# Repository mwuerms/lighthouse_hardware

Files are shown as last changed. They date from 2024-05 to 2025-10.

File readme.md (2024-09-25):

# Lighthouse - Hardware

## basic concept

+ lighthouse
+ buoy: hand sender, ble advertising

## lighthouse - electronics

### main board

- RF-MCU: nRF52840: [NINA-B302-00B Module](https://www.mouser.ch/ProductDetail/377-NINA-B302-00B) (ublox)
  - SWDIO connector (50 mil header)
  - RTC (optional): i2c + backup battery CV
  - sound module: [DFPlayer mini](https://wiki.dfrobot.com/DFPlayer_Mini_SKU_DFR0299)
  - display 1: display time
  - display 2: lighting, simulate sunrise
  - Buttons
  - Sensors
    - ambient light sensor (ALS)
      - [VEML7700-TR](https://www.mouser.ch/ProductDetail/78-VEML7700-TR)
      - [TMD37253M](https://www.mouser.ch/ProductDetail/985-TMD37253M) much more than ALS, also proximity and color sensor
      - also maybe [VEML3235](https://www.mouser.ch/ProductDetail/78-VEML3235), [VEML6035](https://www.mouser.ch/ProductDetail/78-VEML6035)
    - rh sensor
      - [SHT40-AD1B-R2](https://www.mouser.ch/ProductDetail/403-SHT40-AD1B-R2)
    - p sensor
      - [DPS368XTSA1](https://www.mouser.ch/ProductDetail/726-DPS368XTSA1)
    - microphone, maybe implement a "do I snore" functionality
      - [CMM-4030DT-26354-TR](https://www.mouser.ch/ProductDetail/490-CMM4030DT26354TR)

### display

- addressable LEDs: [IN-PI22TAT5R5G5B](https://www.mouser.ch/ProductDetail/743-IN-PI22TAT5R5G5B)

### buoy - electronics

- RF-MCU: nRF52811 module [ISP1907-LL-RS](https://www.mouser.ch/ProductDetail/359-ISP1907-LL-RS)
- battery CR2032
- vibration sensor [Adafruit 2384](https://www.mouser.ch/ProductDetail/485-2384)
- button PTS526 [PTS526 SK15 SMTR2 LFS](https://www.mouser.ch/ProductDetail/611-PTS526SK15SMR2L)
- SWDIO connector (50 mil header)

#### schematics

buoy will be soldered together using wire only, no pcb for this.

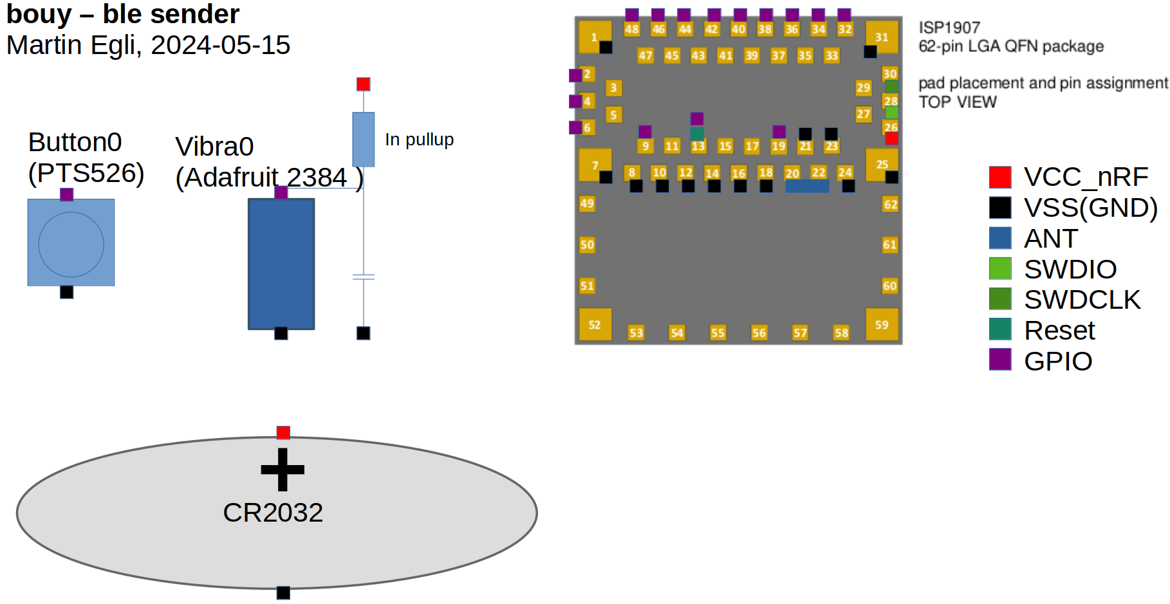
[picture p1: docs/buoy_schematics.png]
buoy_schematics


# links

just a collection of (maybe) useful links

- [markdown cheat sheet](https://www.markdownguide.org/cheat-sheet/)

# ideas

- add many sensors like
  - microphone, analyze snoring
- add memory/flash to log
  - sensor values
  - events
  - errors, ...

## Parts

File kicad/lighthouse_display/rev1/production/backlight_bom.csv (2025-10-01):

Designator | Footprint | Quantity | Value | LCSC Part #
C1 | 0603 | 1 | CL10B104KA8NNNC | C1590
C10 | 0603 | 1 | CL10B104KA8NNNC | C1590
C11 | 0805 | 1 | CL21B105KAFNFNE | C1712
C2 | 0805 | 1 | CL21B103KBANNNC | C1710
C3 | 0603 | 1 | 0603B512K500NT | C1587
C4 | 0805 | 1 | CL21B105KAFNFNE | C1712
C5 | 0805 | 1 | CL21B103KBANNNC | C1710
C6 | 0603 | 1 | CL10B104KA8NNNC | C1590
C7 | 0805 | 1 | CL21B103KBANNNC | C1710
C8 | 0603 | 1 | CL10B104KA8NNNC | C1590
C9 | 0603 | 1 | CL10B104KA8NNNC | C1590
D1 | 1206 | 1 | KT-1206Y | C2298
D10 | 1206 | 1 | KT-1206Y | C2298
D100 | SOD-323F | 1 | PMEG4010CEJ,115 | C50704
D101 | 1206 | 1 | XL-3216WWC | C965830
D102 | 1206 | 1 | XL-3216WWC | C965830
D103 | 1206 | 1 | XL-3216WWC | C965830
D104 | 1206 | 1 | XL-3216WWC | C965830
D105 | 1206 | 1 | XL-3216WWC | C965830
D106 | 1206 | 1 | XL-3216WWC | C965830
D11 | 1206 | 1 | KT-1206Y | C2298
D12 | 1206 | 1 | KT-1206R | C49018
D13 | 1206 | 1 | KT-1206R | C49018
D14 | 1206 | 1 | KT-1206Y | C2298
D15 | 1206 | 1 | KT-1206Y | C2298
D16 | 1206 | 1 | KT-1206R | C49018
D17 | 1206 | 1 | KT-1206R | C49018
D18 | 1206 | 1 | KT-1206Y | C2298
D19 | 1206 | 1 | KT-1206Y | C2298
D2 | 1206 | 1 | KT-1206Y | C2298
D20 | 1206 | 1 | KT-1206Y | C2298
D21 | 1206 | 1 | KT-1206R | C49018
D22 | 1206 | 1 | KT-1206R | C49018
D23 | 1206 | 1 | KT-1206Y | C2298
D24 | 1206 | 1 | KT-1206Y | C2298
D25 | 1206 | 1 | KT-1206R | C49018
D26 | 1206 | 1 | KT-1206R | C49018
D27 | 1206 | 1 | KT-1206Y | C2298
D28 | 1206 | 1 | KT-1206Y | C2298
D29 | 1206 | 1 | KT-1206R | C49018
D3 | 1206 | 1 | KT-1206Y | C2298
D30 | 1206 | 1 | KT-1206R | C49018
D31 | 1206 | 1 | KT-1206Y | C2298
D32 | 1206 | 1 | KT-1206Y | C2298
D33 | 1206 | 1 | KT-1206R | C49018
D34 | 1206 | 1 | KT-1206R | C49018
D35 | 1206 | 1 | KT-1206Y | C2298
D36 | 1206 | 1 | KT-1206Y | C2298
D37 | 1206 | 1 | KT-1206Y | C2298
D38 | 1206 | 1 | KT-1206R | C49018
D39 | 1206 | 1 | KT-1206R | C49018
D4 | 1206 | 1 | KT-1206Y | C2298
D40 | 1206 | 1 | KT-1206Y | C2298
D41 | 1206 | 1 | KT-1206Y | C2298
D42 | 1206 | 1 | KT-1206R | C49018
D43 | 1206 | 1 | KT-1206R | C49018
D44 | 1206 | 1 | KT-1206Y | C2298
D45 | 1206 | 1 | KT-1206Y | C2298
D46 | 1206 | 1 | KT-1206R | C49018
D47 | 1206 | 1 | KT-1206R | C49018
D48 | 1206 | 1 | KT-1206Y | C2298
D49 | 1206 | 1 | KT-1206Y | C2298
D5 | 1206 | 1 | KT-1206Y | C2298
D50 | 1206 | 1 | KT-1206Y | C2298
D51 | 1206 | 1 | KT-1206R | C49018
D52 | 1206 | 1 | KT-1206R | C49018
D53 | 1206 | 1 | KT-1206Y | C2298
D54 | 1206 | 1 | KT-1206Y | C2298
D55 | 1206 | 1 | KT-1206Y | C2298
D56 | 1206 | 1 | KT-1206Y | C2298
D57 | 1206 | 1 | KT-1206R | C49018
D58 | 1206 | 1 | KT-1206R | C49018
D59 | 1206 | 1 | KT-1206R | C49018
D6 | 1206 | 1 | KT-1206Y | C2298
D60 | 1206 | 1 | KT-1206R | C49018
D61 | 1206 | 1 | KT-1206R | C49018
D62 | 1206 | 1 | KT-1206R | C49018
D63 | 1206 | 1 | KT-1206R | C49018
D64 | 1206 | 1 | XL-3216WWC | C965830
D65 | 1206 | 1 | XL-3216WWC | C965830
D66 | 1206 | 1 | XL-3216WWC | C965830
D67 | 1206 | 1 | XL-3216WWC | C965830
D68 | 1206 | 1 | XL-3216WWC | C965830
D69 | 1206 | 1 | XL-3216WWC | C965830
D7 | 1206 | 1 | KT-1206Y | C2298
D70 | 1206 | 1 | XL-3216WWC | C965830
D71 | 1206 | 1 | XL-3216WWC | C965830
D72 | 1206 | 1 | XL-3216WWC | C965830
D73 | 1206 | 1 | XL-3216WWC | C965830
D74 | 1206 | 1 | XL-3216WWC | C965830
D75 | 1206 | 1 | XL-3216WWC | C965830
D76 | 1206 | 1 | XL-3216WWC | C965830
D77 | 1206 | 1 | XL-3216WWC | C965830
D78 | 1206 | 1 | XL-3216WWC | C965830
D79 | 1206 | 1 | XL-3216WWC | C965830
D8 | 1206 | 1 | KT-1206R | C49018
D80 | 1206 | 1 | XL-3216WWC | C965830
D81 | 1206 | 1 | XL-3216WWC | C965830
D82 | 1206 | 1 | XL-3216WWC | C965830
D83 | 1206 | 1 | XL-3216WWC | C965830
D84 | 1206 | 1 | XL-3216WWC | C965830
D85 | 1206 | 1 | XL-3216WWC | C965830
D86 | 1206 | 1 | XL-3216WWC | C965830
D87 | 1206 | 1 | XL-3216WWC | C965830
D88 | 1206 | 1 | XL-3216WWC | C965830
D89 | 1206 | 1 | XL-3216WWC | C965830
D9 | 1206 | 1 | KT-1206R | C49018
D90 | 1206 | 1 | XL-3216WWC | C965830
D91 | 1206 | 1 | XL-3216WWC | C965830
D92 | 1206 | 1 | XL-3216WWC | C965830
D93 | 1206 | 1 | XL-3216WWC | C965830
D94 | 1206 | 1 | XL-3216WWC | C965830
D95 | 1206 | 1 | XL-3216WWC | C965830
D96 | 1206 | 1 | XL-3216WWC | C965830
D97 | 1206 | 1 | XL-3216WWC | C965830
D98 | 1206 | 1 | XL-3216WWC | C965830
D99 | 1206 | 1 | XL-3216WWC | C965830
IC1 | WSON-6-EP | 1 | OPT3004DNPR | C2655153
R1 | 0603 | 1 | 0603WAJ0135T5E | C12647
R10 | 0603 | 1 | 0603WAF1004T5E | C22935
R11 | 0603 | 1 | 0603WAF1004T5E | C22935
R12 | 0603 | 1 | 0603WAF2002T5E | C4184
R2 | 0603 | 1 | 0603WAF5102T5E | C23196
R3 | 0603 | 1 | 0603WAF1004T5E | C22935
R4 | 0603 | 1 | 0603WAF6802T5E | C23231
R5 | 0603 | 1 | 0603WAF1004T5E | C22935
R8 | 0603 | 1 | 0603WAF1004T5E | C22935
R9 | 0603 | 1 | 0603WAF1004T5E | C22935
U2 | WQFN-16-EP | 1 | TPS61176RTER | C117008
U3 | DFN-4-EP | 1 | SHTC3-TR-10KS | C2880044

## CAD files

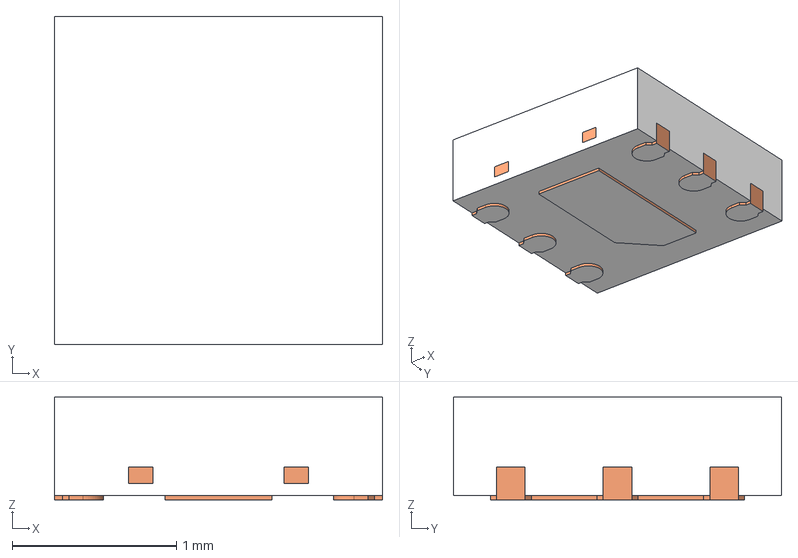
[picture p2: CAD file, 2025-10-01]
kicad/lighthouse.3d/USON-6.stp
2.00 x 2.00 x 0.625 mm
BODY-SON
FRAME-DNP0006A
PIN1-ID
DIE
BOND_WIRE_AF0
BOND_WIRE_AF1
BOND_WIRE_AF2
BOND_WIRE_AF3
BOND_WIRE_AF4
BOND_WIRE_AF5

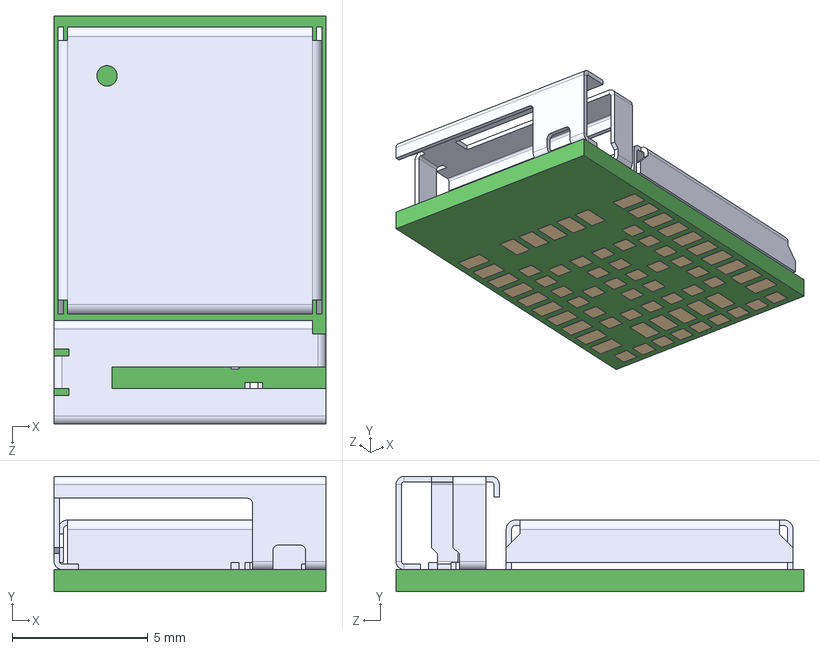
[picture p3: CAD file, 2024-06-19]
kicad/lighthouse_base/NINA-B312/NINA-B312.step
10.0 x 4.23 x 15.0 mm

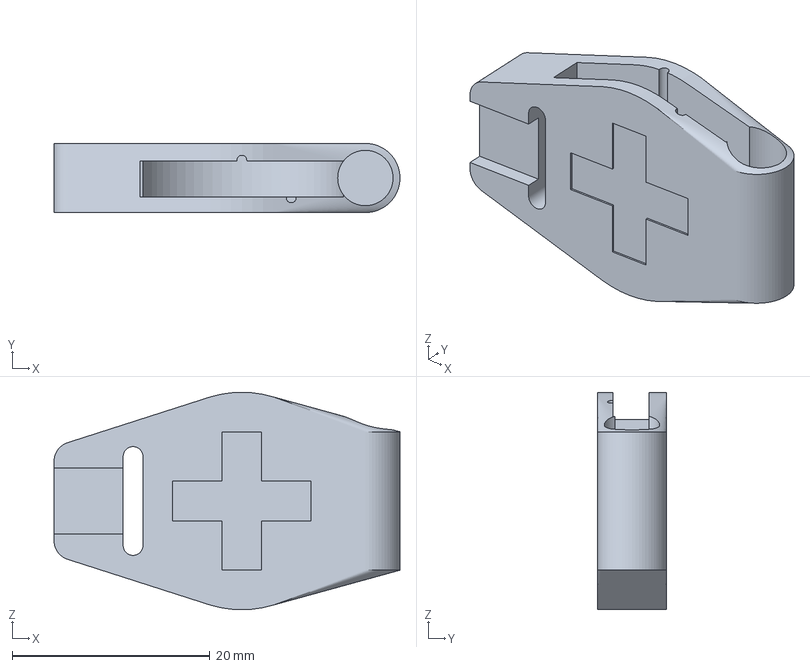
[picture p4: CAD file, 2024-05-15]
scad/buoy/buoy_v1.0.3mf
35.0 x 7.00 x 22.0 mm

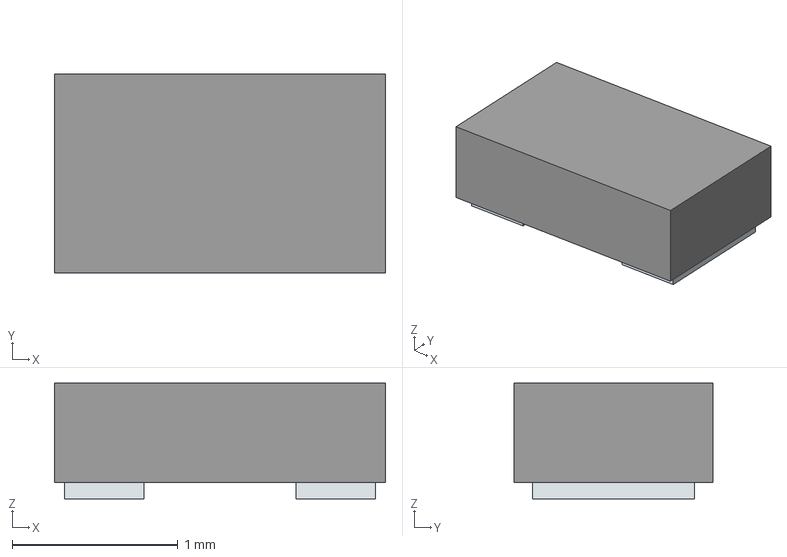
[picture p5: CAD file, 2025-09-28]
kicad/lighthouse.3d/9HT11-32.768KDZB-T.stp
2.00 x 1.20 x 0.7 mm
Pins

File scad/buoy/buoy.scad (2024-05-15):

/**
 * Martin Egli
 * 2024-03-20
 * buoy: sender on the wrist
 */
use <parts.scad>

module buoy(show_parts = 1, loc_res = 32) {
    // create buoy case
    difference() {
        hull() {
            translate([0, 0, -7])
            cylinder(d = 22, h = 7, $fn = loc_res);
            translate([+(20+5)/2, -14/2, -7/2])
            rotate([-90, 0, 0])
            cylinder(d = 7, h = 14, $fn = loc_res);
            translate([-17, -8/2, -7])
            cylinder(d = 4, h = 7, $fn = loc_res);
            translate([-17, +8/2, -7])
            cylinder(d = 4, h = 7, $fn = loc_res);
        }
    
        // cut out parts
        translate([-15, 0, -2])
        rotate([0, 0, 90])
        isp1907_cut();
        
        // CR2032
        hull() {
            translate([0, 0, -3.4-2])
            cr2032_cut(loc_res);
            translate([0, -12, -3.4-2])
            cr2032_cut(loc_res);
        }
        // battery contacts
        hull() {
            translate([0, -12, -1.7])
            rotate([-90, 0, 0])
            cylinder(d = 1, h = 22, $fn = loc_res);
            translate([0, -12, -1.7-1])
            rotate([-90, 0, 0])
            cylinder(d = 1, h = 22, $fn = loc_res);
        }
        hull() {
            translate([5, -12, -1.7-2])
            rotate([-90, 0, 0])
            cylinder(d = 1, h = 20, $fn = loc_res);
            translate([5, -12, -1.7-3.8])
            rotate([-90, 0, 0])
            cylinder(d = 1, h = 20, $fn = loc_res);
        }
        // + on bottom
        translate([0, 0, -(8-0.2)]) {
            translate([-14/2, -4/2, 0])
            cube([14, 4, 1]);
            translate([-4/2, -14/2, 0])
            cube([4, 14, 1]);
        }
        
        translate([+(20+5)/2, -11/2+0.2, -7/2])
        rotate([0, 90, 90])
        vibrasensorAdafruit2384_cut(loc_res);
        
        translate([-17, -(2*1.27), -6.3])
        rotate([-90, 0, 90])
        swd50milHeader_cut();
        
        translate([-14, -(2*1.27), -6.3])
        rotate([-90, 0, 90])
        swd50milHeader_cut();
        // cut buttonPTS526
        translate([-6/2, -6/2, -0.5])
        cube([6, 6, 2]);
        
        // cut outs for wires
        hull() {
            translate([-11, -9/2, -(7+1)])
            cylinder(d = 2, h = 7+2, $fn = loc_res);
            translate([-11, +9/2, -(7+1)])
            cylinder(d = 2, h = 7+2, $fn = loc_res);
        }
        hull() {
            translate([-11, 0, -1])
            cylinder(d = 2, h = 2, $fn = loc_res);
            translate([+9, 0, -1])
            cylinder(d = 2, h = 2, $fn = loc_res);
        }
        translate([+9, 0, -7/2])
        cylinder(d = 2, h = 4, $fn = loc_res);
    }
    
    // show components
    if(show_parts) {
        translate([-15, 0, -2])
        rotate([0, 0, 90])
        isp1907();

        translate([0, 0, -3.2-2])
        cr2032();

        translate([+(20+5)/2, -11/2, -7/2])
        rotate([0, 90, 90])
        vibrasensorAdafruit2384(con_len = 4);

        translate([-17, -(2*1.27), -6.3])
        rotate([-90, 0, 90])
        swd50milHeader();

        translate([0, 0, -0.5])
        buttonPTS526();
    }
}
buoy(0, 64); // print 1x

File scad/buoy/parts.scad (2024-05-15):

/**
* Martin Egli
* 2024-03-20
* a mockup for a SIP1907 (nRF52811) module with CR2032
*/
module origin(col = "Red", len = 10, loc_res = 4) {
    color(col)
    cylinder(d2 = .8, d1 = 0, h = len, $fn = loc_res);
}

module isp1907(loc_res = 32) {
    // MCU part, with connections, light part
    color("DarkGray")
    translate([-4, 0, 0])
    cube([8, 4, 1]);
    // antenna part
    color("Gray")
    translate([-4, -4, 0])
    cube([8, 4, 1]);
}

module isp1907_cut() {
    translate([-8.6/2, -8.6/2, 0])
    cube([8.6, 8.6, 3]);
}

module cr2032(loc_res = 32) {
    color("Silver") {
        cylinder(d = 17.7, h = 3.2, $fn = loc_res);
        cylinder(d = 20.0, h = 2.5, $fn = loc_res);
        translate([0, 0, 2.5])
        cylinder(d1 = 20.0, d2 = 19.0, h = 0.5, $fn = loc_res);
        // +
        translate([-5, -1, -0.1])
        cube([10, 2, 1]);
        translate([-1, -5, -0.1])
        cube([2, 10, 1]);
    }
}

module cr2032_cut(loc_res = 32) {
    cylinder(d = 20.6, h = 3.2+0.4, $fn = loc_res);
}

module tiltsensorRB231x2(show_origin = 1, loc_res = 32) {
    if(show_origin) {
        origin();
    }
    rotate([0, 90, 0]) 
    translate([-5/2, 0, -1]) {
        color("Silver") {
            hull() {
                translate([0, 0, 0])
                cylinder(d = 4, h = 11.4, $fn = loc_res);
                translate([0, 0, 11.4])
                cylinder(d1 = 4, d2 = 3, h = 1, $fn = loc_res);
            }
            translate([1, -2.5/2, 1])
            cube([4, 2.5, 0.5]);
        }
        color("Black")
        translate([0, 0, 0])
        cylinder(d = 5, h = 1, $fn = loc_res);
        color("Gold") {
        translate([-1, -0.8/2, -4.2])
        cube([10.7-5/2, 0.8, 0.8]);
        translate([-1, -0.8/2, -4.2])
        cube([0.8, 0.8, 5]);
        }
    }
}

module vibrasensorAdafruit2384(show_origin= 1, con_len = 12, loc_res = 32) {
    if(show_origin) {
        origin();
    }
    color("DarkBlue")
    translate([0, 0, 0])
    cylinder(d = 5, h = 11, $fn = loc_res);
    translate([-1.2, -0.4/2,  -con_len])
    cube([0.4, 0.4, con_len]);
    translate([+0.8, -0.4/2,  -con_len])
    cube([0.4, 0.4, con_len]);
}
module vibrasensorAdafruit2384_cut(loc_res = 32) {
    translate([0, 0, -4])
    cylinder(d = 5.6, h = 11+4, $fn = loc_res);
}

module swd50milHeader(loc_res = 32) {
    color("Silver")
    for(n = [0: 1: 4])
    translate([n*1.27, 0, -2])
    cylinder(d = 0.6, h = 4, $fn = loc_res);
    color("Black")
    translate([-1.27/2, -1.27/2, 0])
    cube([1.27*5, 1.27, 1.9]);
}

module swd50milHeader_cut() {
    translate([-1.27/2-0.15, -1.27/2-0.15, -(4-1.9)])
    cube([1.27*5+0.3, 1.27+0.3, 4.5]); // h = 1.9
}

module buttonPTS526(col = "Silver", loc_res = 32) {
// origin in the middle, at the bottom
    color(col) {
        hull() {
            translate([-3/2, -4.8/2, 0])
            cube([3, 4.8, 1]);
            translate([-4.8/2, -3/2, 0])
            cube([4.8, 3, 1]);
        }
        translate([0, 0, 0])
        cylinder(d =2, h = 1.5, $fn = loc_res);
    }
}
*buttonPTS526();

// origin: center
// detailed version
module led1206_detailed(col = "Red", loc_res = 32) {
    difference() {
        union() {
            color(col)
            translate([-2/2, -1.6/2, 0.3])
            cube([2, 1.6, 0.4]);
            color("White")
            translate([-3.2/2, -1.6/2, 0])
            cube([3.2, 1.6, 0.3]);
            translate([-3.25/2, -1.5/2, -0.01])
            cube([0.6, 1.5, 0.32]);
            translate([+(3.25/2-0.6), -1.5/2, -0.01])
            cube([0.6, 1.5, 0.32]);
        }
        translate([-3.2/2, 0, -0.2])
        cylinder(d = 0.4, h = 1, $fn = loc_res);
        translate([+3.2/2, 0, -0.2])
        cylinder(d = 0.4, h = 1, $fn = loc_res);
    }
}

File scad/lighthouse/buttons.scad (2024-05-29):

/**
 * Martin Egli
 * 2024-05-28
 * buttons for lighthouse
 */
use <hexagonparts.scad>

hex_rad = 8/2;
/* calculate hexagon center positions
 * r: radius, use "hex_rad"
 * n: index in x axis
 * m: index in y axis
 * even columns
 * dxeven = n*2*r*cos(30)
 * dyeven = m*3/2*r
 * odd columns
 * dxodd = n*3/2*r
 * dyodd = (m-1/2)*r*cos(30)
 * /
dx_even_factor = 3/2*hex_rad; // see dxeven = m*3*r
dy_even_factor = 2*hex_rad*cos(30); // see dyeven = n*2*r*cos(30)
dx_odd_factor = 3/2*hex_rad; // see dxodd = m*3/2*r
dy_odd_factor = hex_rad*cos(30); // see dyodd = (2n+1)*r*cos(30)
*/
dx_even_factor = 3/2*hex_rad; // see dxeven = m*3*r
dy_even_factor = 2*hex_rad*cos(30); // see dyeven = n*2*r*cos(30)
dx_odd_factor = 3/2*hex_rad; // see dxodd = m*3/2*r
dy_odd_factor = hex_rad*cos(30); // see dyodd = (2n+1)*r*cos(30)

module place_button(x_pos = 0, y_pos = 0) {
    if((x_pos % 2) == 0) {
        // even column
        translate([x_pos*dx_even_factor, y_pos*dy_even_factor, 0]) {
            hexagon_element(hex_rad1 = 12/2, hex_hi1 = 0.5);
            hull() {
                hexagon_element(hex_rad1 = 10/2, hex_hi1 = 2);
                hexagon_element(hex_rad1 = 8/2, hex_hi1 = 2.5);
            }
        }
    }
    else {
        // odd column
        translate([x_pos*dx_odd_factor, (2*y_pos-1)*dy_odd_factor, 0]) {
            hexagon_element(hex_rad1 = 12/2, hex_hi1 = 0.5);
            hull() {
                hexagon_element(hex_rad1 = 10/2, hex_hi1 = 2);
                hexagon_element(hex_rad1 = 8/2, hex_hi1 = 2.5);
            }
        }
    }
}
*place_button(1, 0);

module place_long_button(x_pos = 0, y_pos = 0, x_wid = 1) {
    if((x_pos % 2) == 0) {
        // even column
        hull() {
            translate([x_pos*dx_even_factor, y_pos*dy_even_factor, 0])
            hexagon_element(hex_rad1 = 12/2, hex_hi1 = 0.5);
            translate([(x_pos+x_wid)*dx_even_factor, y_pos*dy_even_factor, 0])
            hexagon_element(hex_rad1 = 12/2, hex_hi1 = 0.5);
        }
        hull() {
            translate([x_pos*dx_even_factor, y_pos*dy_even_factor, 0]) {
                hexagon_element(hex_rad1 = 10/2, hex_hi1 = 2);
                hexagon_element(hex_rad1 = 8/2, hex_hi1 = 2.5);
            }
            translate([(x_pos+x_wid)*dx_even_factor, y_pos*dy_even_factor, 0]) {
                hexagon_element(hex_rad1 = 10/2, hex_hi1 = 2);
                hexagon_element(hex_rad1 = 8/2, hex_hi1 = 2.5);
            }
        }
    }
    else {
        // odd column
        hull() {
            translate([x_pos*dx_odd_factor, (2*y_pos-1)*dy_odd_factor, 0])
            hexagon_element(hex_rad1 = 12/2, hex_hi1 = 0.5);
            translate([(x_pos+x_wid)*dx_odd_factor, (2*y_pos-1)*dy_odd_factor, 0])
            hexagon_element(hex_rad1 = 12/2, hex_hi1 = 0.5);
        }
        hull() {
            translate([x_pos*dx_odd_factor, (2*y_pos-1)*dy_odd_factor, 0]) {
                hexagon_element(hex_rad1 = 10/2, hex_hi1 = 2);
                hexagon_element(hex_rad1 = 8/2, hex_hi1 = 2.5);
            }
            translate([(x_pos+x_wid)*dx_odd_factor, (2*y_pos-1)*dy_odd_factor, 0]) {
                hexagon_element(hex_rad1 = 10/2, hex_hi1 = 2);
                hexagon_element(hex_rad1 = 8/2, hex_hi1 = 2.5);
            }
        }
    }
}

place_long_button(3, -2, 3);

module place_button_cutout(x_pos = 0, y_pos = 0) {
    if((x_pos % 2) == 0) {
        // even column
        translate([x_pos*dx_even_factor, y_pos*dy_even_factor, 0])
        hexagon_element(hex_rad1 = 10.5/2, hex_hi1 = 10);
    }
    else {
        // odd column
        translate([x_pos*dx_odd_factor, (2*y_pos-1)*dy_odd_factor, 0])
        hexagon_element(hex_rad1 = 10.5/2, hex_hi1 = 10);
    }
}

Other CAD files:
scad/lighthouse/display.scad
scad/buoy/buoy_v1.0.stl
scad/lighthouse/displaytest/displaytest.scad
scad/lighthouse/displaytest/displaytest_rot30.scad
scad/lighthouse/displaytest/parts.scad
scad/lighthouse/electronics.scad
scad/lighthouse/hexagonparts.scad
scad/lighthouse/ledparts.scad
scad/lighthouse/lighthousecase.scad
scad/lighthouse/lighthouseexport.scad
scad/lighthouse/m3screw.scad
scad/lighthouse/panels.scad
scad/lighthouse/pcbs.scad

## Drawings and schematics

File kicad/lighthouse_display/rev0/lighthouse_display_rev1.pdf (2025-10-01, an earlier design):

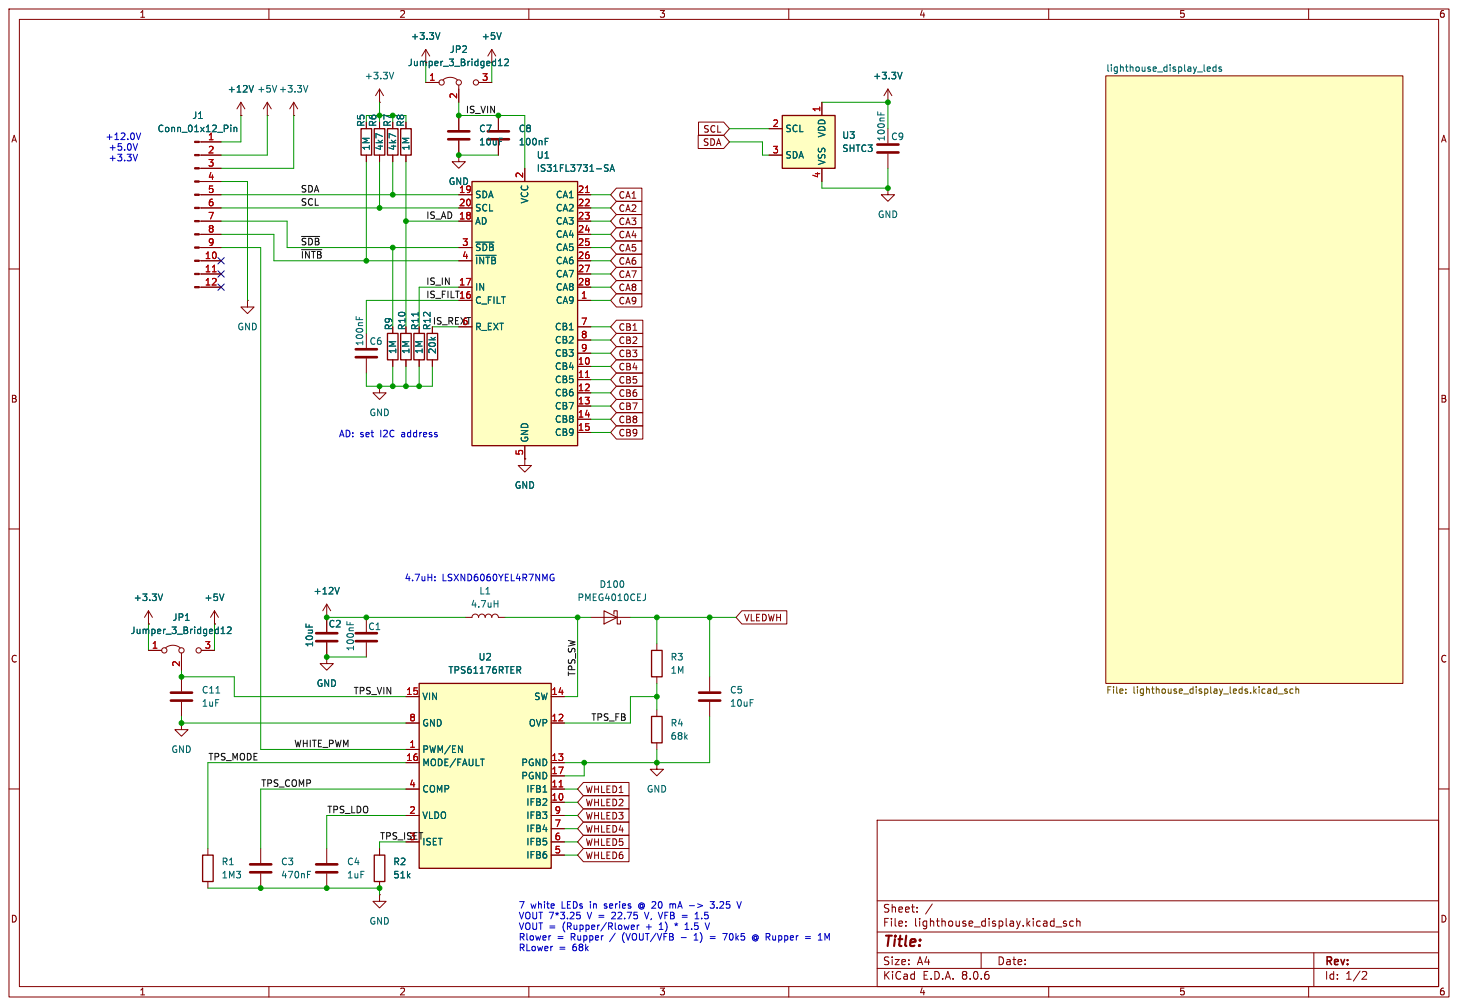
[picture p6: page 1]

2 SCL 20 CA1 21 CA2 22 CA3 23 CA4 24 CA5 25 CA6 26 CA7 27 CA8 28 ~{SDB} 3 ~{INTB} 4 GND

Id: 1/2 Title: File: lighthouse_display.kicad_sch Sheet: /

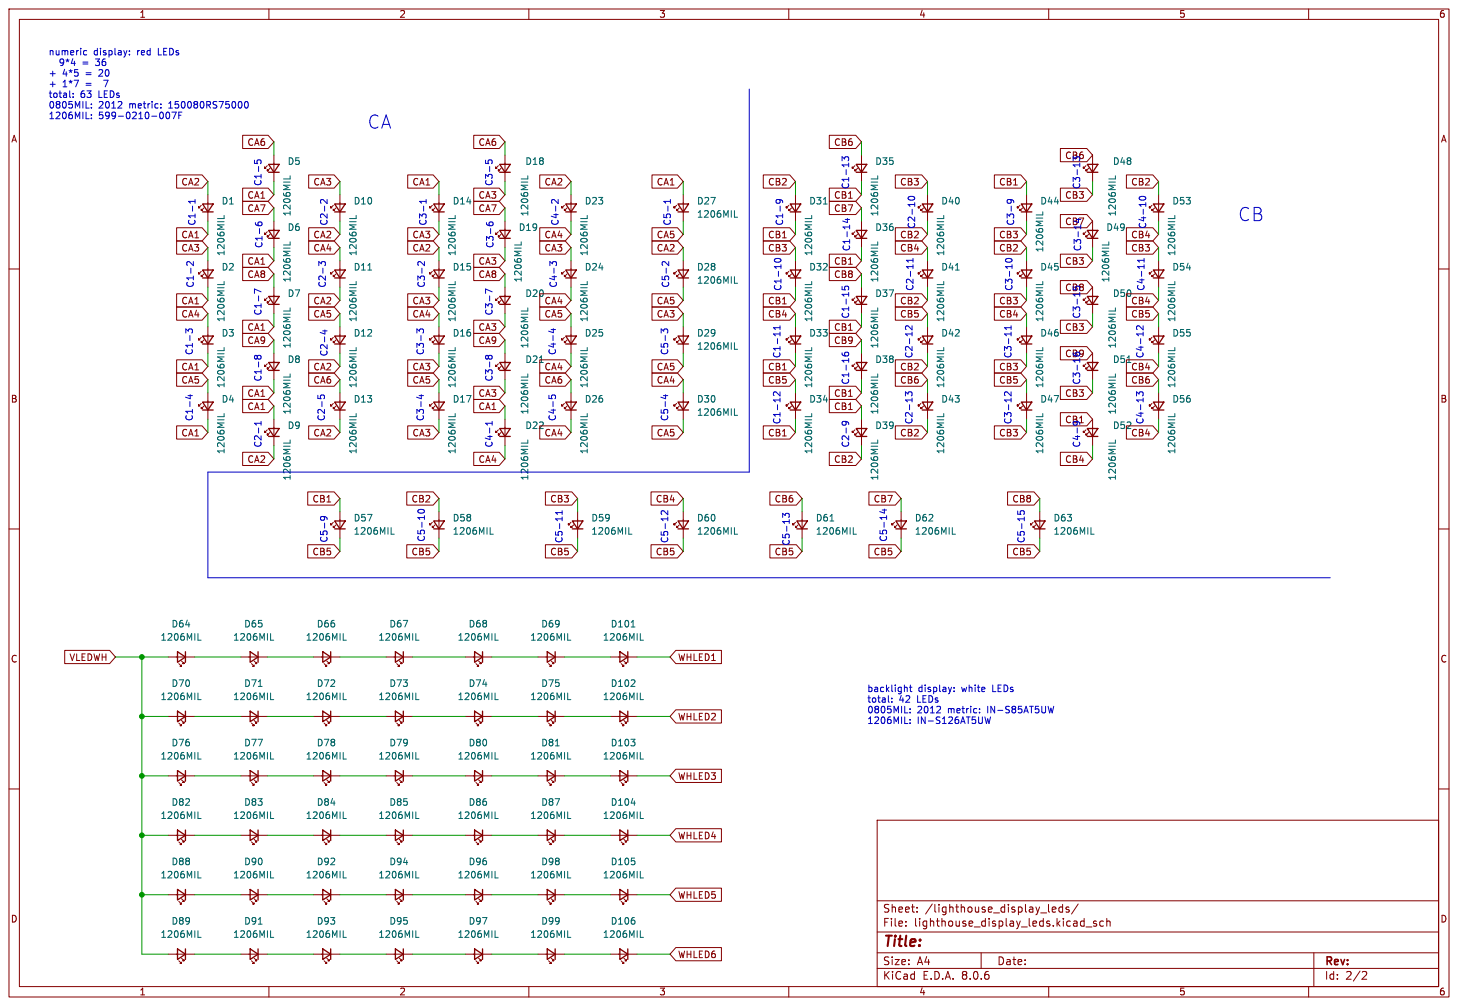
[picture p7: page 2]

total: 42 LEDs 0805MIL: 2012 metric: IN-S85AT5UW

Id: 2/2 Title: File: lighthouse_display_leds.kicad_sch Sheet: /lighthouse_display_leds/

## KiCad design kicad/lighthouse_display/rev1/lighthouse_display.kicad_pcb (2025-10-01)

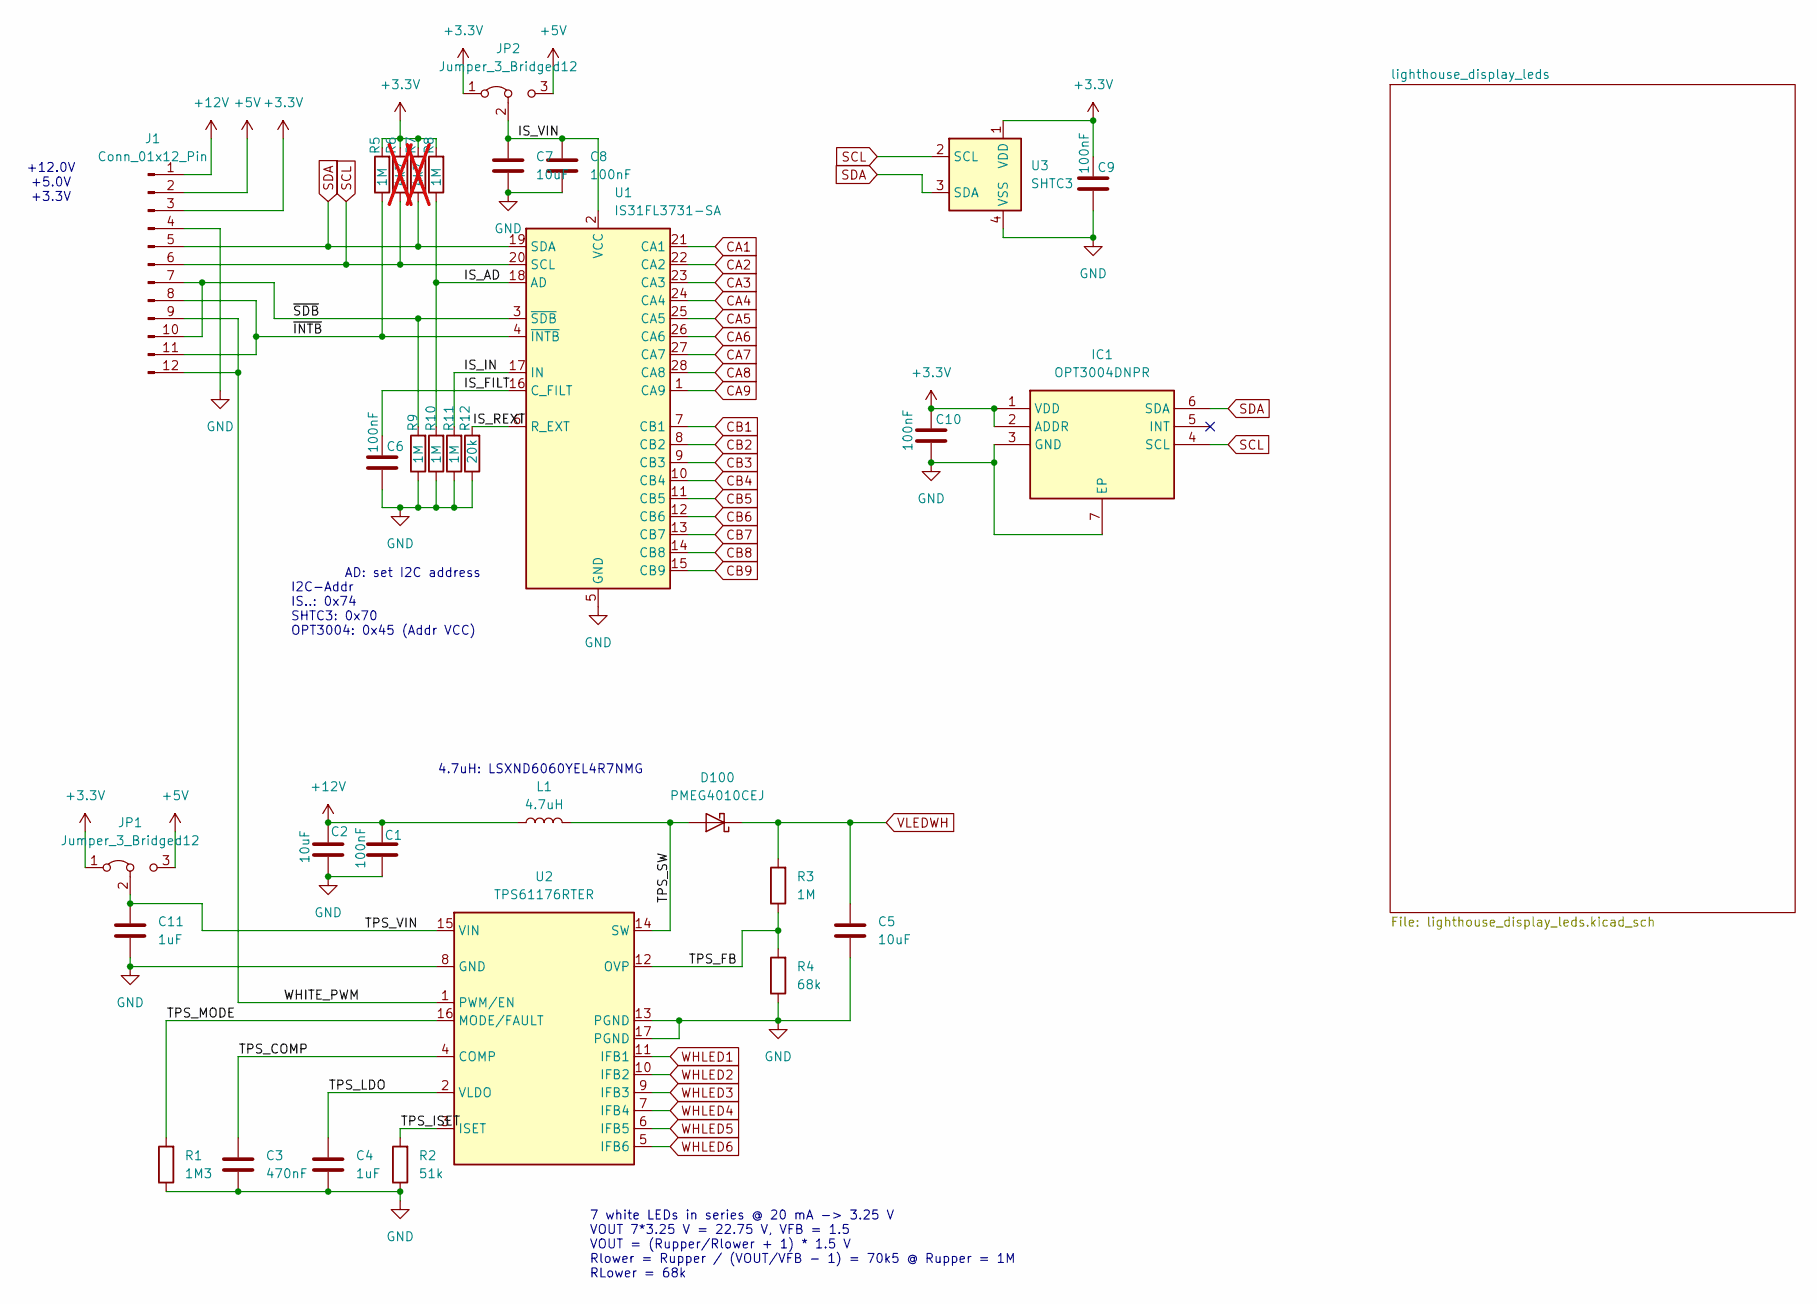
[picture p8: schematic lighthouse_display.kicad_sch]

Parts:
C1, C6, C8, C9, C10: 100nF; C_0603_1608Metric_Pad1.08x0.95mm_HandSolder
C2, C5, C7: 10uF; C_0805_2012Metric_Pad1.18x1.45mm_HandSolder
C3: 470nF; C_0603_1608Metric_Pad1.08x0.95mm_HandSolder
C4, C11: 1uF; C_0805_2012Metric_Pad1.18x1.45mm_HandSolder
D100: PMEG4010CEJ; D_SOD-323F
IC1: OPT3004DNPR; SON65P200X200X65-7N-D; Mouser Part Number 595-OPT3004DNPR
J1: Conn_01x12_Pin; con_1x12_1.27mm_long_pads
JP1, JP2: Jumper_3_Bridged12; SolderJumper-3_P1.3mm_Bridged12_RoundedPad1.0x1.5mm
L1: 4.7uH; L_Taiyo-Yuden_NR-60xx_HandSoldering
R1: 1M3; R_0603_1608Metric_Pad0.98x0.95mm_HandSolder
R2: 51k; R_0603_1608Metric_Pad0.98x0.95mm_HandSolder
R3, R5, R8, R9, R10, R11: 1M; R_0603_1608Metric_Pad0.98x0.95mm_HandSolder
R4: 68k; R_0603_1608Metric_Pad0.98x0.95mm_HandSolder
R6, R7: 4k7; R_0603_1608Metric_Pad0.98x0.95mm_HandSolder; not fitted
R12: 20k; R_0603_1608Metric_Pad0.98x0.95mm_HandSolder
U1: IS31FL3731-SA; SSOP-28_5.3x10.2mm_P0.65mm
U2: TPS61176RTER; Texas_RTE0016D_WQFN-16-1EP_3x3mm_P0.5mm_EP0.8x0.8mm
U3: SHTC3; Sensirion_DFN-4-1EP_2x2mm_P1mm_EP0.7x1.6mm

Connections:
+3.3V: C9.1, C10.1, IC1.1 (VDD), IC1.2 (ADDR), J1.3, JP1.1 (A), JP2.1 (A), R5.2, R6.2, R7.2, R8.2, U3.1 (VDD)
+5V: J1.2, JP1.3 (B), JP2.3 (B)
+12V: C1.1, C2.1, J1.1, L1.1
/IS_AD: R8.1, R10.2, U1.18 (AD)
/IS_FILT: C6.1, U1.16 (C_FILT)
/IS_IN: R11.2, U1.17 (IN)
/IS_REXT: R12.2, U1.6 (R_EXT)
/IS_VIN: C7.1, C8.1, JP2.2 (C), U1.2 (VCC)
/TPS_COMP: C3.1, U2.4 (COMP)
/TPS_FB: R3.1, R4.2, U2.12 (OVP)
/TPS_ISET: R2.2, U2.3 (ISET)
/TPS_LDO: C4.1, U2.2 (VLDO)
/TPS_MODE: R1.2, U2.16 (MODE/FAULT)
/TPS_SW: D100.2 (A), L1.2, U2.14 (SW)
/TPS_VIN: C11.1, JP1.2 (C), U2.15 (VIN)
/WHITE_PWM: J1.9, J1.12, U2.1 (PWM/EN)
/~INTB: J1.8, J1.11, R5.1, U1.4 (~INTB)
/~SDB: J1.7, J1.10, R9.2, U1.3 (~SDB)
CA1: U1.21 (CA1); also elsewhere on the board
CA2: U1.22 (CA2); also elsewhere on the board
CA3: U1.23 (CA3); also elsewhere on the board
CA4: U1.24 (CA4); also elsewhere on the board
CA5: U1.25 (CA5); also elsewhere on the board
CA6: U1.26 (CA6); also elsewhere on the board
CA7: U1.27 (CA7); also elsewhere on the board
CA8: U1.28 (CA8); also elsewhere on the board
CA9: U1.1 (CA9); also elsewhere on the board
CB1: U1.7 (CB1); also elsewhere on the board
CB2: U1.8 (CB2); also elsewhere on the board
CB3: U1.9 (CB3); also elsewhere on the board
CB4: U1.10 (CB4); also elsewhere on the board
CB5: U1.11 (CB5); also elsewhere on the board
CB6: U1.12 (CB6); also elsewhere on the board
CB7: U1.13 (CB7); also elsewhere on the board
CB8: U1.14 (CB8); also elsewhere on the board
CB9: U1.15 (CB9); also elsewhere on the board
GND: C1.2, C2.2, C3.2, C4.2, C5.2, C6.2, C7.2, C8.2, C9.2, C10.2, C11.2, IC1.3 (GND), IC1.7 (EP), J1.4, R1.1, R2.1, R4.1, R9.1, R10.1, R11.1, R12.1, U1.5 (GND), U2.8 (GND), U2.13 (PGND), U2.17 (PGND), U3.4 (VSS)
SCL: IC1.4 (SCL), J1.6, R6.1, U1.20 (SCL), U3.2 (SCL)
SDA: IC1.6 (SDA), J1.5, R7.1, U1.19 (SDA), U3.3 (SDA)
VLEDWH: C5.1, D100.1 (K), R3.2; also elsewhere on the board
WHLED1: U2.11 (IFB1); also elsewhere on the board
WHLED2: U2.10 (IFB2); also elsewhere on the board
WHLED3: U2.9 (IFB3); also elsewhere on the board
WHLED4: U2.7 (IFB4); also elsewhere on the board
WHLED5: U2.6 (IFB5); also elsewhere on the board
WHLED6: U2.5 (IFB6); also elsewhere on the board

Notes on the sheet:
AD: set I2C address
4.7uH: LSXND6060YEL4R7NMG
I2C-Addr IS..: 0x74 SHTC3: 0x70 OPT3004: 0x45 (Addr VCC)
7 white LEDs in series @ 20 mA -> 3.25 V VOUT 7*3.25 V = 22.75 V, VFB = 1.5 VOUT = (Rupper/Rlower + 1) * 1.5 V Rlower = Rupper / (VOUT/VFB - 1) = 70k5 @ Rupper = 1M RLower = 68k
+12.0V +5.0V +3.3V

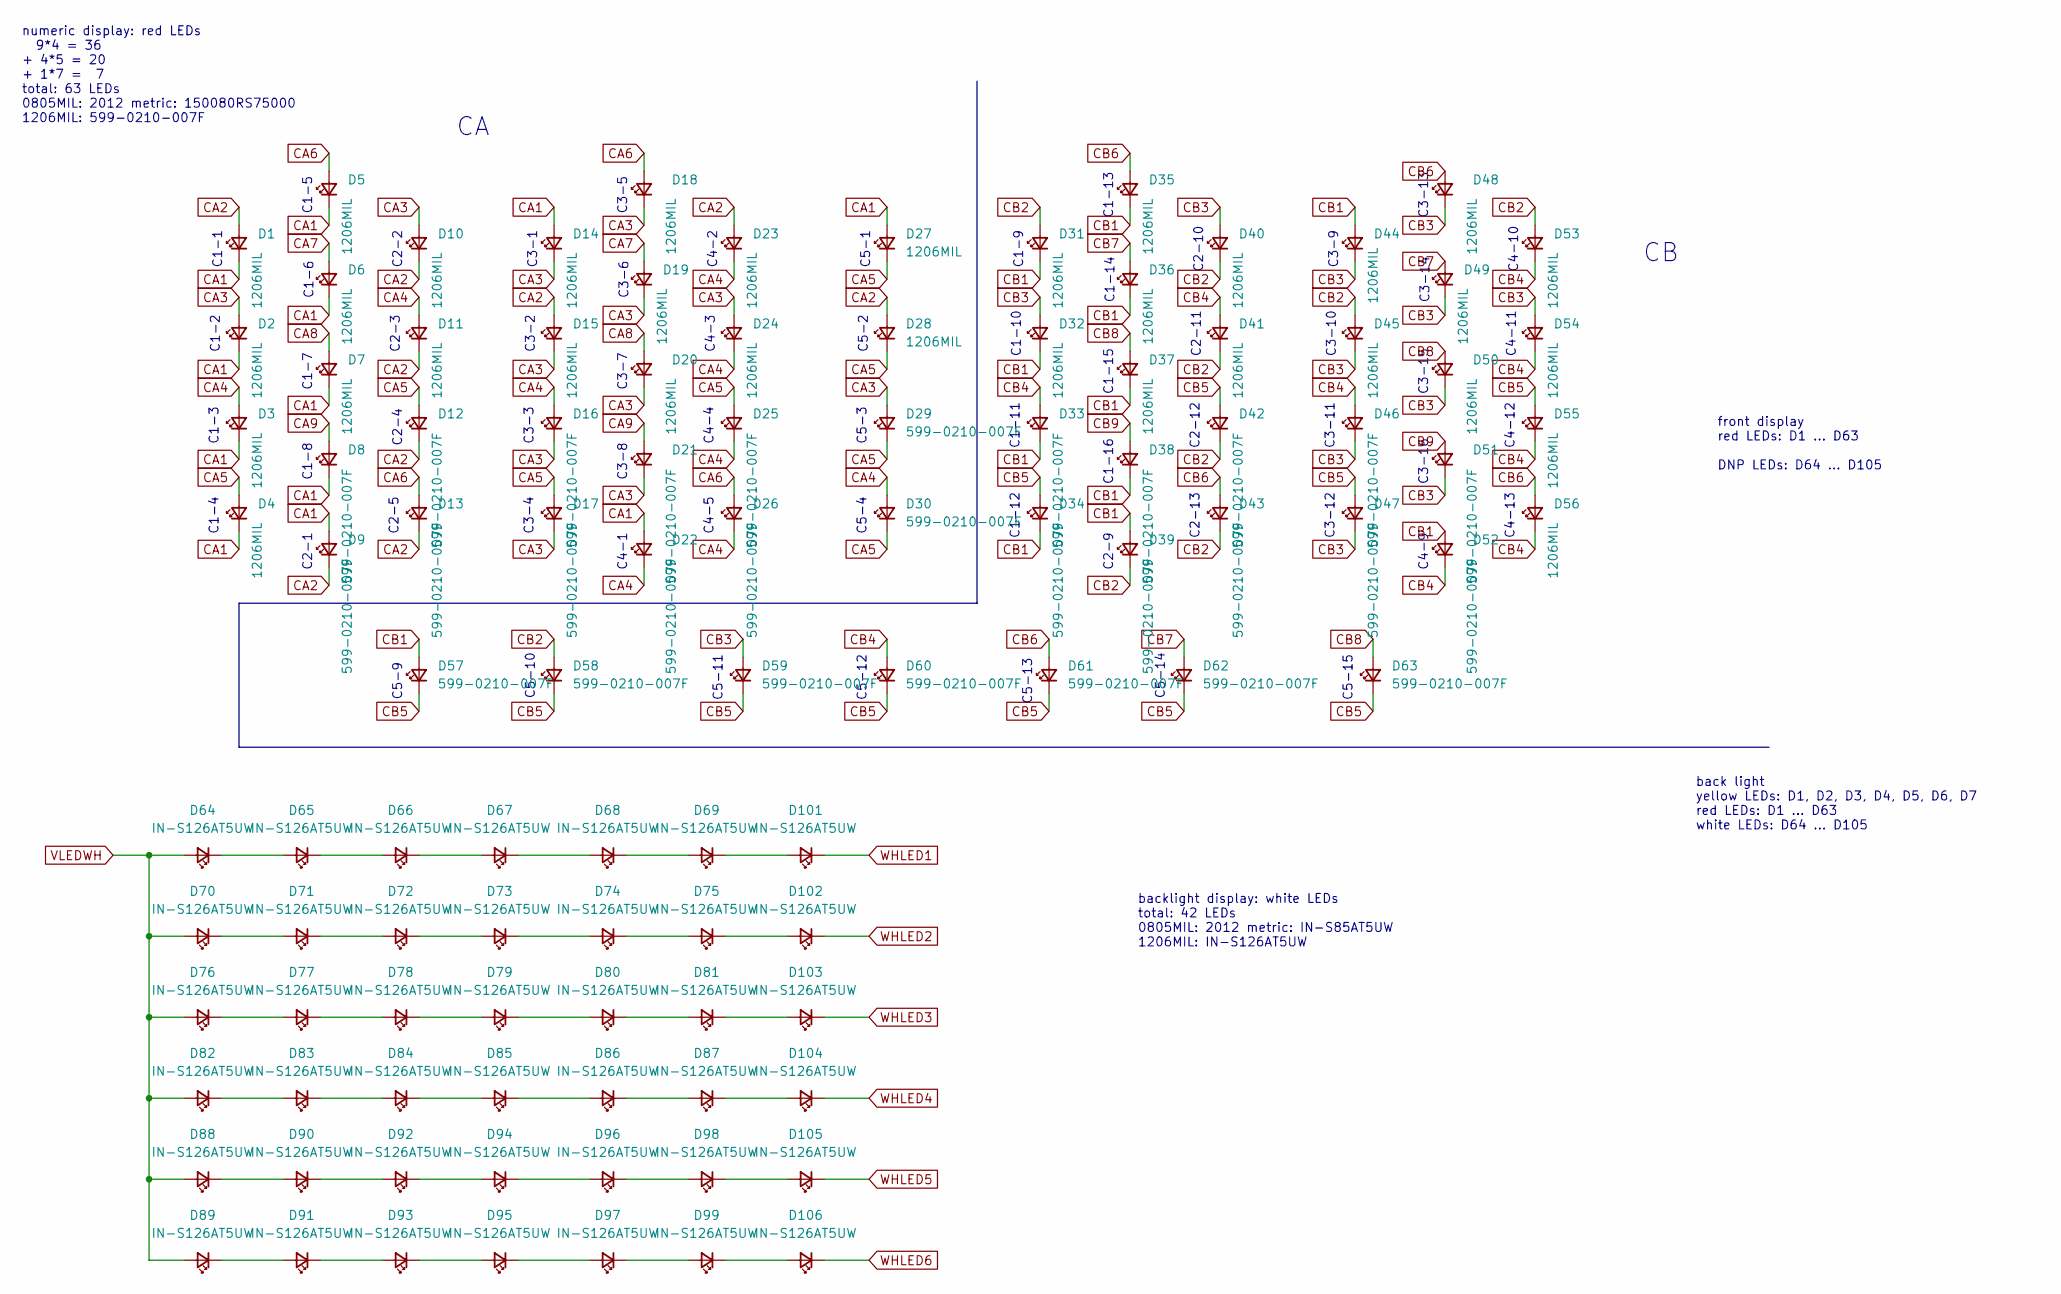
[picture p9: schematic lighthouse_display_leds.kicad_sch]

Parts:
D1, D2, D3, D4, D5, D6, D7, D10, D11, D14, D15, D18, D19, D20, D23, D24, D27, D28, D31, D32, D35, D36, D37, D40, D41, D44, D45, D48, D49, D50, D53, D54, D55, D56: 1206MIL; LED_1206_3216Metric_Pad1.42x1.75mm_HandSolder
D8, D9, D12, D13, D16, D17, D21, D22, D25, D26, D29, D30, D33, D34, D38, D39, D42, D43, D46, D47, D51, D52, D57, D58, D59, D60, D61, D62, D63: 599-0210-007F; LED_1206_3216Metric_Pad1.42x1.75mm_HandSolder
D64, D65, D66, D67, D68, D69, D70, D71, D72, D73, D74, D75, D76, D77, D78, D79, D80, D81, D82, D83, D84, D85, D86, D87, D88, D89, D90, D91, D92, D93, D94, D95, D96, D97, D98, D99, D101, D102, D103, D104, D105, D106: IN-S126AT5UW; LED_1206_3216Metric_Pad1.42x1.75mm_HandSolder

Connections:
CA1: D1.1 (K), D2.1 (K), D3.1 (K), D4.1 (K), D5.1 (K), D6.1 (K), D7.1 (K), D8.1 (K), D9.2 (A), D14.2 (A), D22.2 (A), D27.2 (A); also elsewhere on the board
CA2: D1.2 (A), D9.1 (K), D10.1 (K), D11.1 (K), D12.1 (K), D13.1 (K), D15.2 (A), D23.2 (A), D28.2 (A); also elsewhere on the board
CA3: D2.2 (A), D10.2 (A), D14.1 (K), D15.1 (K), D16.1 (K), D17.1 (K), D18.1 (K), D19.1 (K), D20.1 (K), D21.1 (K), D24.2 (A), D29.2 (A); also elsewhere on the board
CA4: D3.2 (A), D11.2 (A), D16.2 (A), D22.1 (K), D23.1 (K), D24.1 (K), D25.1 (K), D26.1 (K), D30.2 (A); also elsewhere on the board
CA5: D4.2 (A), D12.2 (A), D17.2 (A), D25.2 (A), D27.1 (K), D28.1 (K), D29.1 (K), D30.1 (K); also elsewhere on the board
CA6: D5.2 (A), D13.2 (A), D18.2 (A), D26.2 (A); also elsewhere on the board
CA7: D6.2 (A), D19.2 (A); also elsewhere on the board
CA8: D7.2 (A), D20.2 (A); also elsewhere on the board
CA9: D8.2 (A), D21.2 (A); also elsewhere on the board
CB1: D31.1 (K), D32.1 (K), D33.1 (K), D34.1 (K), D35.1 (K), D36.1 (K), D37.1 (K), D38.1 (K), D39.2 (A), D44.2 (A), D52.2 (A), D57.2 (A); also elsewhere on the board
CB2: D31.2 (A), D39.1 (K), D40.1 (K), D41.1 (K), D42.1 (K), D43.1 (K), D45.2 (A), D53.2 (A), D58.2 (A); also elsewhere on the board
CB3: D32.2 (A), D40.2 (A), D44.1 (K), D45.1 (K), D46.1 (K), D47.1 (K), D48.1 (K), D49.1 (K), D50.1 (K), D51.1 (K), D54.2 (A), D59.2 (A); also elsewhere on the board
CB4: D33.2 (A), D41.2 (A), D46.2 (A), D52.1 (K), D53.1 (K), D54.1 (K), D55.1 (K), D56.1 (K), D60.2 (A); also elsewhere on the board
CB5: D34.2 (A), D42.2 (A), D47.2 (A), D55.2 (A), D57.1 (K), D58.1 (K), D59.1 (K), D60.1 (K), D61.1 (K), D62.1 (K), D63.1 (K); also elsewhere on the board
CB6: D35.2 (A), D43.2 (A), D48.2 (A), D56.2 (A), D61.2 (A); also elsewhere on the board
CB7: D36.2 (A), D49.2 (A), D62.2 (A); also elsewhere on the board
CB8: D37.2 (A), D50.2 (A), D63.2 (A); also elsewhere on the board
CB9: D38.2 (A), D51.2 (A); also elsewhere on the board
unnamed: D64.1 (K), D65.2 (A)
unnamed: D65.1 (K), D66.2 (A)
unnamed: D66.1 (K), D67.2 (A)
unnamed: D67.1 (K), D68.2 (A)
unnamed: D68.1 (K), D69.2 (A)
unnamed: D70.1 (K), D71.2 (A)
unnamed: D71.1 (K), D72.2 (A)
unnamed: D72.1 (K), D73.2 (A)
unnamed: D73.1 (K), D74.2 (A)
unnamed: D74.1 (K), D75.2 (A)
unnamed: D76.1 (K), D77.2 (A)
unnamed: D77.1 (K), D78.2 (A)
unnamed: D78.1 (K), D79.2 (A)
unnamed: D79.1 (K), D80.2 (A)
unnamed: D80.1 (K), D81.2 (A)
unnamed: D82.1 (K), D83.2 (A)
unnamed: D83.1 (K), D84.2 (A)
unnamed: D84.1 (K), D85.2 (A)
unnamed: D85.1 (K), D86.2 (A)
unnamed: D86.1 (K), D87.2 (A)
unnamed: D88.1 (K), D90.2 (A)
unnamed: D89.1 (K), D91.2 (A)
unnamed: D90.1 (K), D92.2 (A)
unnamed: D91.1 (K), D93.2 (A)
unnamed: D92.1 (K), D94.2 (A)
unnamed: D93.1 (K), D95.2 (A)
unnamed: D94.1 (K), D96.2 (A)
unnamed: D95.1 (K), D97.2 (A)
unnamed: D96.1 (K), D98.2 (A)
unnamed: D97.1 (K), D99.2 (A)
unnamed: D69.1 (K), D101.2 (A)
unnamed: D75.1 (K), D102.2 (A)
unnamed: D81.1 (K), D103.2 (A)
unnamed: D87.1 (K), D104.2 (A)
unnamed: D98.1 (K), D105.2 (A)
unnamed: D99.1 (K), D106.2 (A)
VLEDWH: D64.2 (A), D70.2 (A), D76.2 (A), D82.2 (A), D88.2 (A), D89.2 (A); also elsewhere on the board
WHLED1: D101.1 (K); also elsewhere on the board
WHLED2: D102.1 (K); also elsewhere on the board
WHLED3: D103.1 (K); also elsewhere on the board
WHLED4: D104.1 (K); also elsewhere on the board
WHLED5: D105.1 (K); also elsewhere on the board
WHLED6: D106.1 (K); also elsewhere on the board

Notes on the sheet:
C3-13
C2-1
C5-11
C3-14
C3-5
C3-6
front display red LEDs: D1 ... D63 DNP LEDs: D64 ... D105
C4-13
C1-15
C2-10
C3-16
C4-5
C4-11
C1-13
C1-8
C2-2
C4-4
C3-12
C1-14
C1-10
backlight display: white LEDs total: 42 LEDs 0805MIL: 2012 metric: IN-S85AT5UW 1206MIL: IN-S126AT5UW
C4-10
C3-3
C2-11
C5-13
C4-1
C1-1
C4-3
C2-4
numeric display: red LEDs 9*4 = 36 + 4*5 = 20 + 1*7 = 7 total: 63 LEDs 0805MIL: 2012 metric: 150080RS75000 1206MIL: 599-0210-007F
C1-7
back light yellow LEDs: D1, D2, D3, D4, D5, D6, D7 red LEDs: D1 ... D63 white LEDs: D64 ... D105
C3-15
C1-11
C1-4
C3-2
C3-8
C1-9
C5-2
C3-11

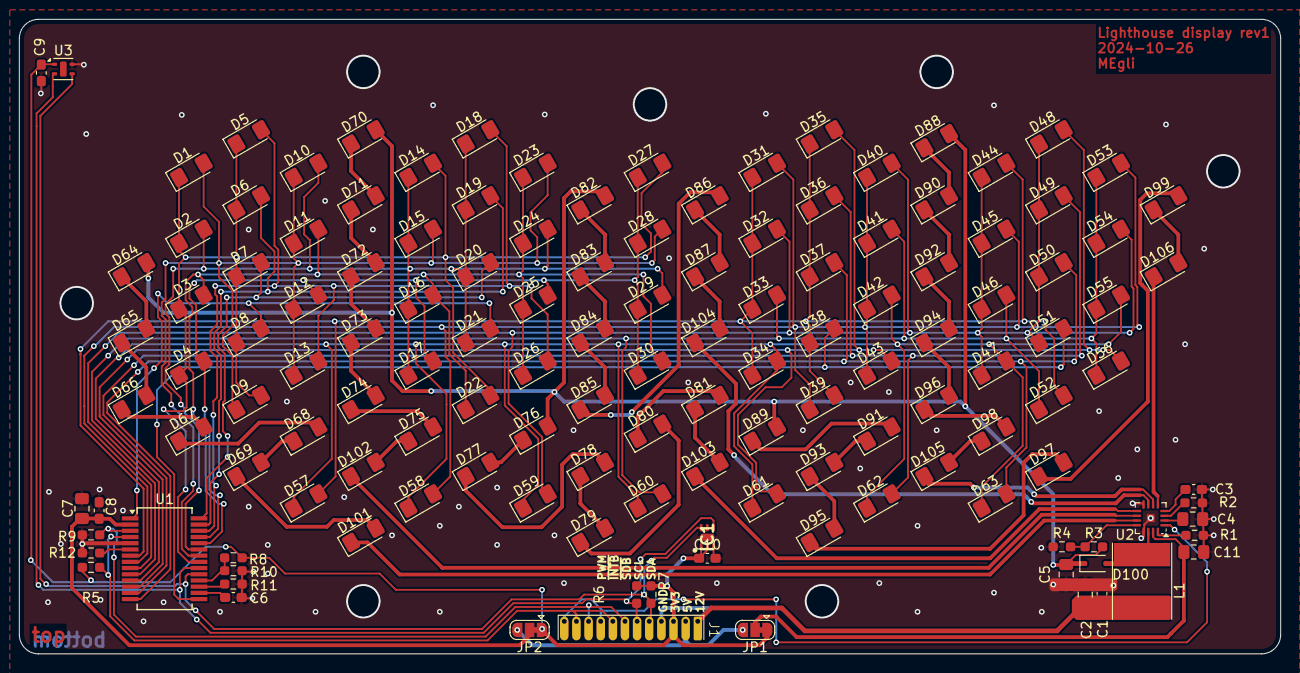
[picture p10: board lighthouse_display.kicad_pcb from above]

Board: 2 copper layers, 132.0 x 66.4 mm, 137 parts (0 on the bottom side), 82 nets.

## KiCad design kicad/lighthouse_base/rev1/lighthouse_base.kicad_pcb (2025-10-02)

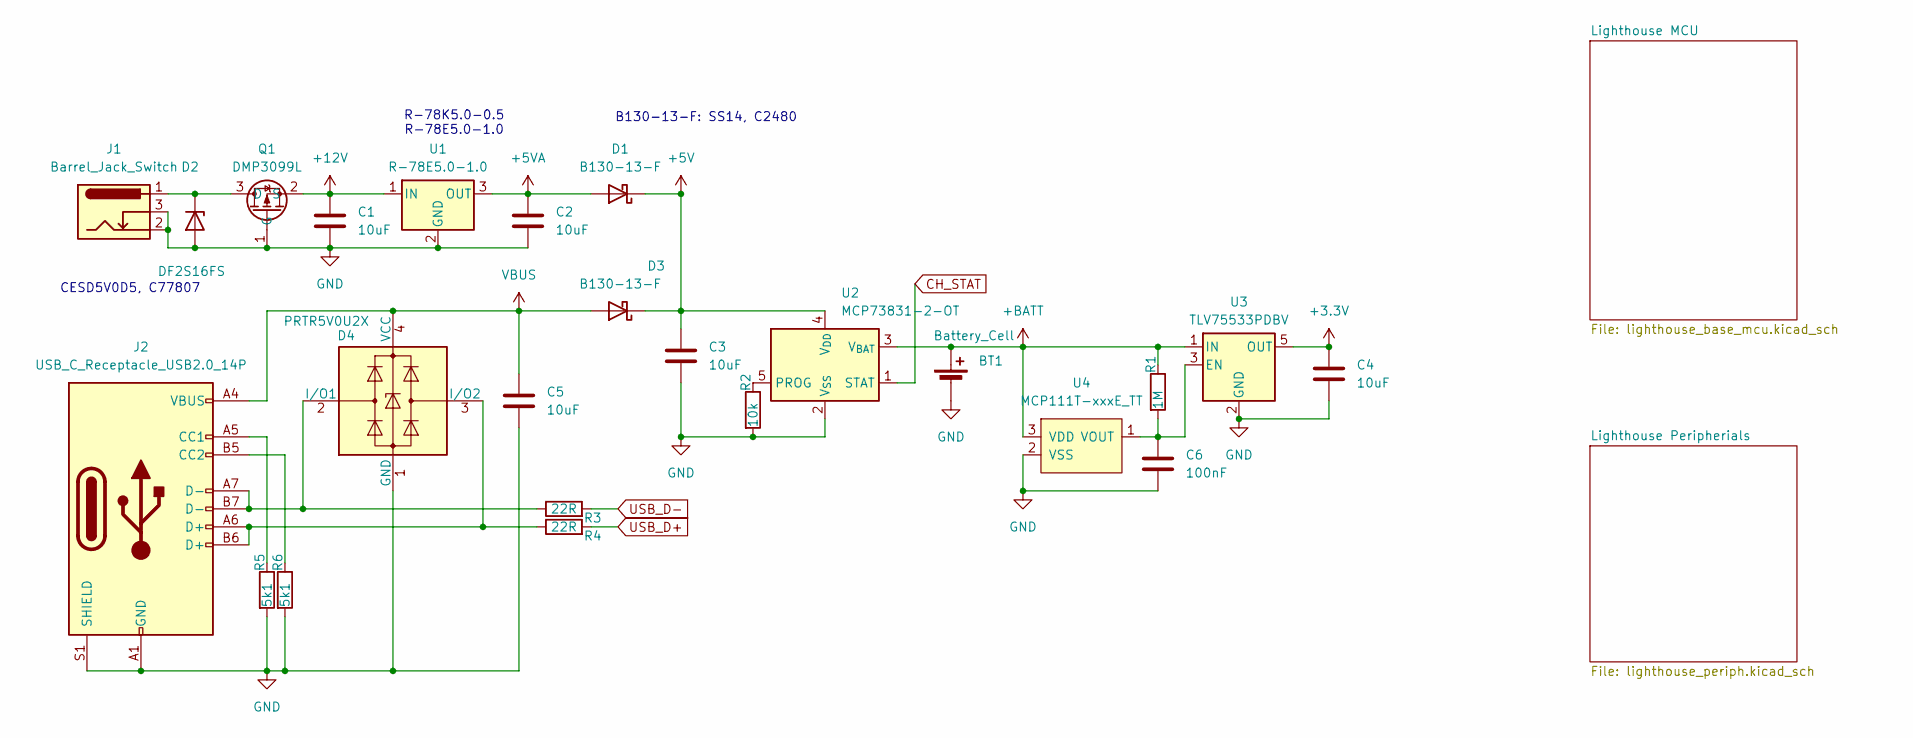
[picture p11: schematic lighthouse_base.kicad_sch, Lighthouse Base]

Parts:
BT1: Battery_Cell; PinHeader_1x02_P2.54mm_Vertical
C1, C2, C3, C4, C5: 10uF; C_0805_2012Metric_Pad1.18x1.45mm_HandSolder
C6: 100nF; C_0603_1608Metric_Pad1.08x0.95mm_HandSolder
D1, D3: B130-13-F; D_SMA_Handsoldering
D2: DF2S16FS; D_SOD-523
D4: PRTR5V0U2X; SOT-143
J1: Barrel_Jack_Switch; BarrelJack_CUI_PJ-063AH_Horizontal
J2: USB_C_Receptacle_USB2.0_14P; USB_C_Receptacle_GCT_USB4110
Q1: DMP3099L; SOT-23-3
R1: 1M; R_0603_1608Metric_Pad0.98x0.95mm_HandSolder
R2: 10k; R_0603_1608Metric_Pad0.98x0.95mm_HandSolder
R3, R4: 22R; R_0603_1608Metric_Pad0.98x0.95mm_HandSolder
R5, R6: 5k1; R_0603_1608Metric_Pad0.98x0.95mm_HandSolder
U1: R-78E5.0-1.0; Converter_DCDC_RECOM_R-78E-0.5_THT
U2: MCP73831-2-OT; SOT-23-5
U3: TLV75533PDBV; SOT-23-5
U4: MCP111T-xxxE_TT; SOT-23-3

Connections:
+3.3V: C4.1, U3.5 (OUT); also elsewhere on the board
+5V: C3.1, D1.1 (K), D3.1 (K), U2.4 (V_{DD}); also elsewhere on the board
+5VA: C2.1, D1.2 (A), U1.3 (OUT); also elsewhere on the board
+12V: C1.1, Q1.2 (S), U1.1 (IN); also elsewhere on the board
+BATT: BT1.1 (+), R1.1, U2.3 (V_{BAT}), U3.1 (IN), U4.3 (VDD); also elsewhere on the board
CH_STAT: U2.1 (STAT); also elsewhere on the board
GND: BT1.2 (-), C1.2, C2.2, C3.2, C4.2, C5.2, C6.2, D2.2 (A), D4.1 (GND), J1.2, J1.3, J2.A1 (GND), J2.A12 (GND), J2.B1 (GND), J2.B12 (GND), J2.S1 (SHIELD), Q1.1 (G), R2.2, R5.2, R6.2, U1.2 (GND), U2.2 (V_{SS}), U3.2 (GND), U4.2 (VSS); also elsewhere on the board
unnamed: D2.1 (K), J1.1, Q1.3 (D)
unnamed: D4.2 (I/O1), J2.A7 (D-), J2.B7 (D-), R3.1
unnamed: D4.3 (I/O2), J2.A6 (D+), J2.B6 (D+), R4.1
unnamed: J2.A5 (CC1), R5.1
unnamed: J2.B5 (CC2), R6.1
unnamed: R2.1, U2.5 (PROG)
unnamed: C6.1, R1.2, U3.3 (EN), U4.1 (VOUT)
USB_D+: R4.2; also elsewhere on the board
USB_D-: R3.2; also elsewhere on the board
VBUS: C5.1, D3.2 (A), D4.4 (VCC), J2.A4 (VBUS), J2.A9 (VBUS), J2.B4 (VBUS), J2.B9 (VBUS); also elsewhere on the board

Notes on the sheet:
B130-13-F: SS14, C2480
R-78K5.0-0.5 R-78E5.0-1.0
CESD5V0D5, C77807

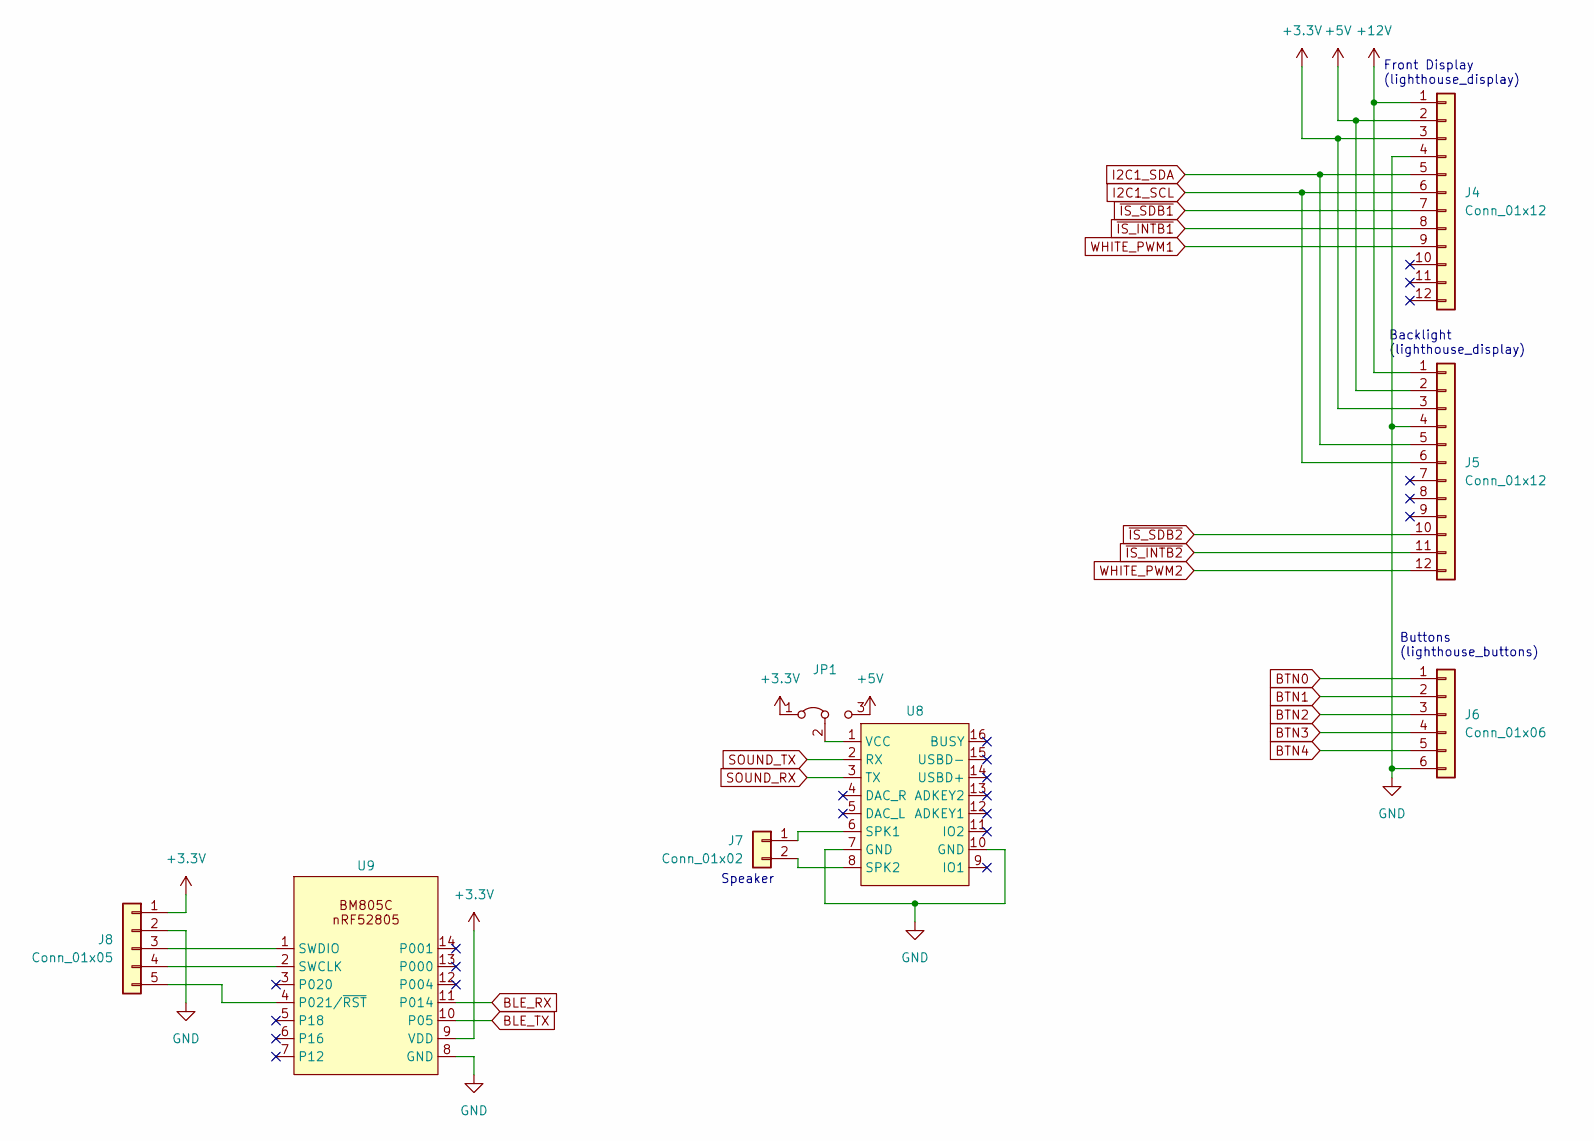
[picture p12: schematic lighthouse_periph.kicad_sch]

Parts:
J4, J5: Conn_01x12; Molex_Picoflex_90325-0012_2x06_P1.27mm_Vertical
J6: Conn_01x06; Molex_Picoflex_90325-0006_2x03_P1.27mm_Vertical
J7: Conn_01x02; PinHeader_1x02_P2.54mm_Vertical
J8: Conn_01x05; PinHeader_1x05_P1.27mm_Vertical
JP1: Jumper_3_Bridged12; SolderJumper-3_P1.3mm_Bridged2Bar12_RoundedPad1.0x1.5mm
U8: DFPlayer_Mini-TF-16P
U9: BC805M

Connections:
+3.3V: J4.3, J5.3, J8.1, JP1.1 (A), U9.9 (VDD); also elsewhere on the board
+5V: J4.2, J5.2, JP1.3 (B); also elsewhere on the board
+12V: J4.1, J5.1; also elsewhere on the board
BLE_RX: U9.11 (P014); also elsewhere on the board
BLE_TX: U9.10 (P05); also elsewhere on the board
BTN0: J6.1; also elsewhere on the board
BTN1: J6.2; also elsewhere on the board
BTN2: J6.3; also elsewhere on the board
BTN3: J6.4; also elsewhere on the board
BTN4: J6.5; also elsewhere on the board
GND: J4.4, J5.4, J6.6, J8.2, U8.7 (GND), U8.10 (GND), U9.8 (GND); also elsewhere on the board
I2C1_SCL: J4.6, J5.6; also elsewhere on the board
I2C1_SDA: J4.5, J5.5; also elsewhere on the board
unnamed: J7.1, U8.6 (SPK1)
unnamed: J7.2, U8.8 (SPK2)
unnamed: J8.3, U9.1 (SWDIO)
unnamed: J8.4, U9.2 (SWCLK)
unnamed: J8.5, U9.4 (P021/~RST)
unnamed: JP1.2 (C), U8.1 (VCC)
SOUND_RX: U8.3 (TX); also elsewhere on the board
SOUND_TX: U8.2 (RX); also elsewhere on the board
WHITE_PWM1: J4.9; also elsewhere on the board
WHITE_PWM2: J5.12; also elsewhere on the board
~IS_INTB1: J4.8; also elsewhere on the board
~IS_INTB2: J5.11; also elsewhere on the board
~IS_SDB1: J4.7; also elsewhere on the board
~IS_SDB2: J5.10; also elsewhere on the board

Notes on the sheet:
Front Display (lighthouse_display)
Speaker
Buttons (lighthouse_buttons)
Backlight (lighthouse_display)

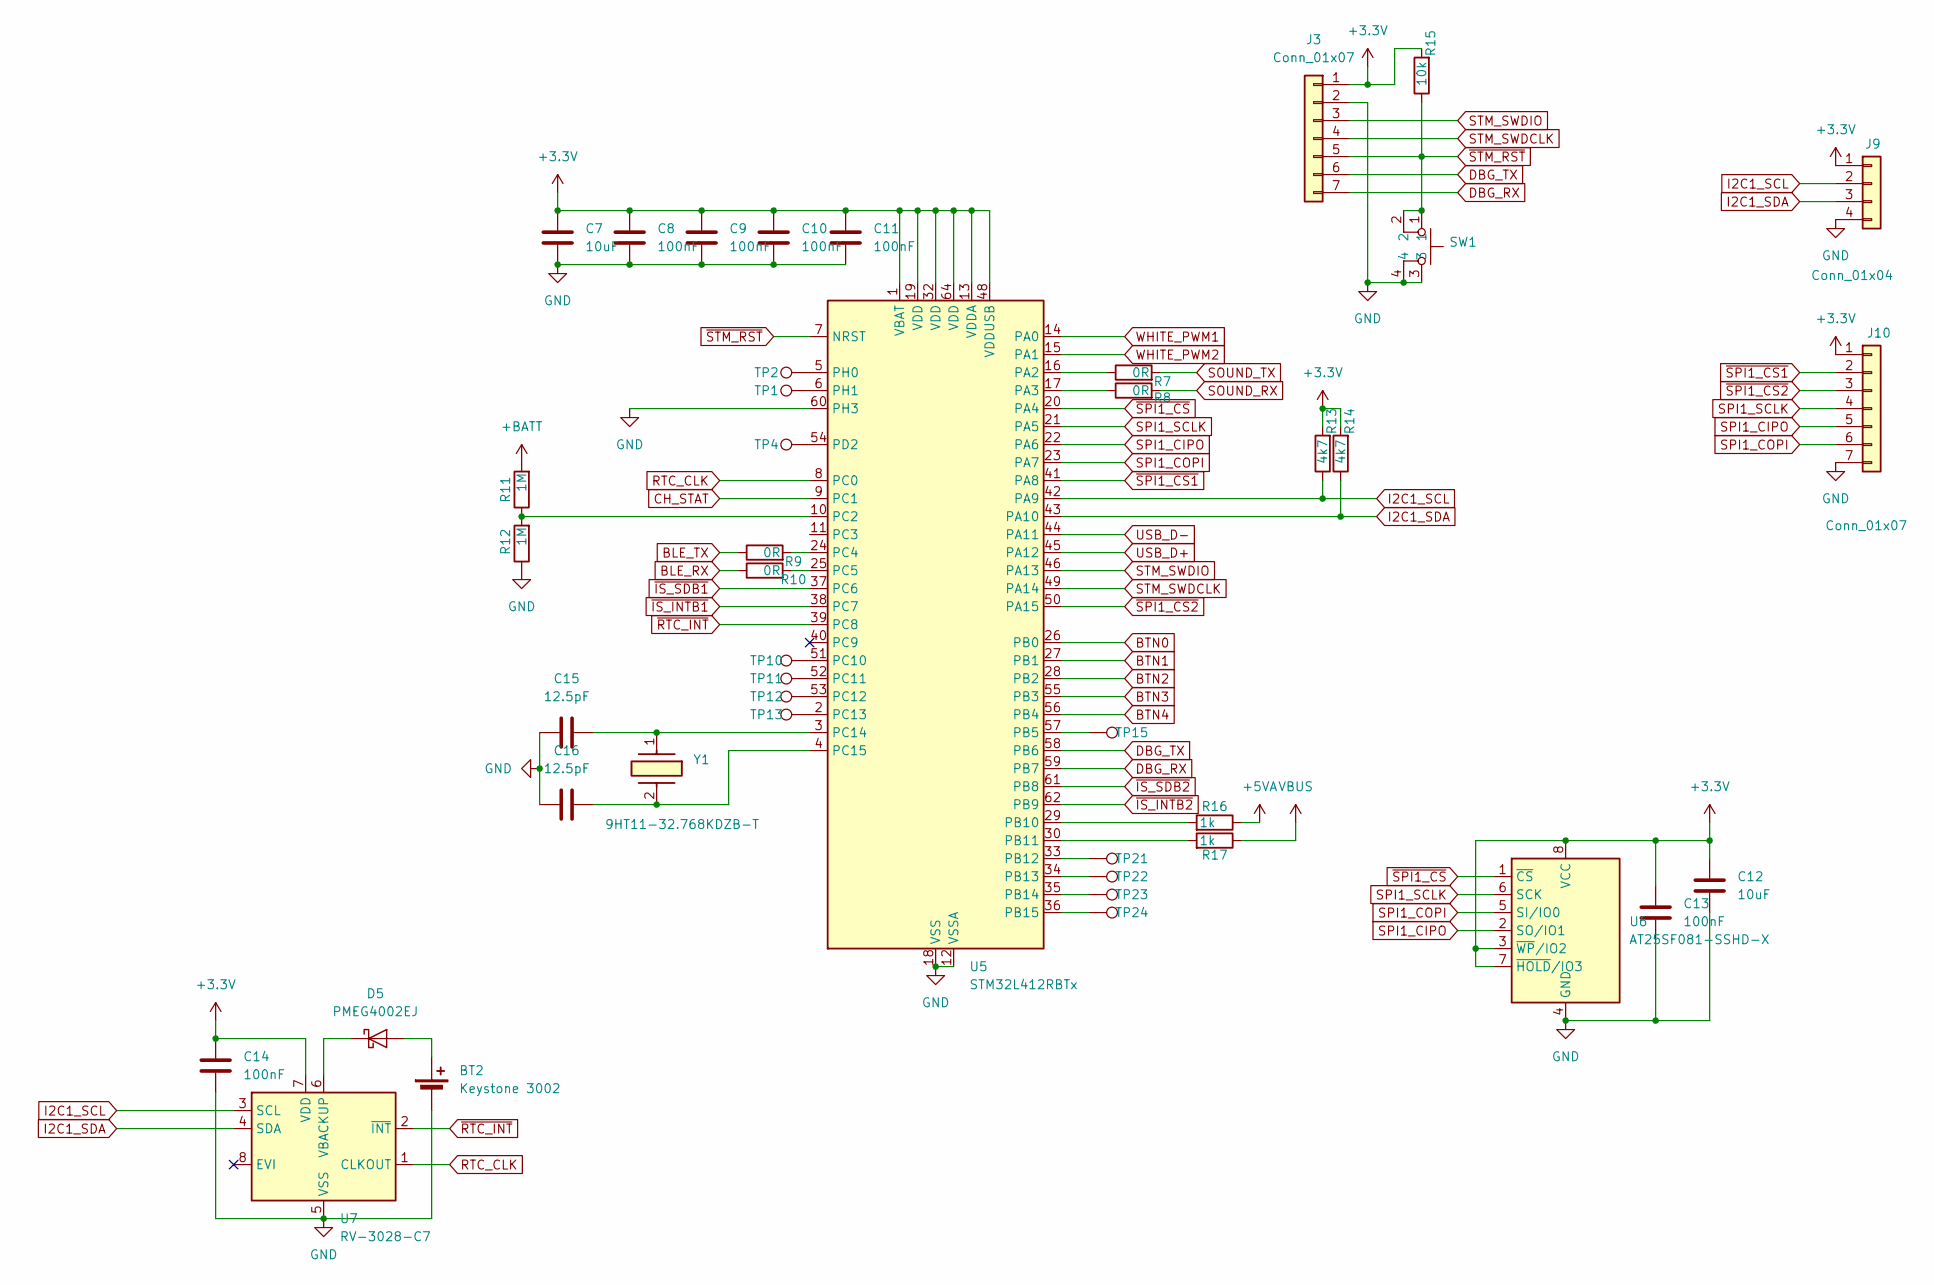
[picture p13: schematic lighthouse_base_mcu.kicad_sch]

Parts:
BT2: Keystone 3002; BatteryHolder_Keystone_3002_1x2032
C7, C12: 10uF; C_0805_2012Metric_Pad1.18x1.45mm_HandSolder
C8, C9, C10, C11, C13, C14: 100nF; C_0603_1608Metric_Pad1.08x0.95mm_HandSolder
C15, C16: 12.5pF; C_0603_1608Metric_Pad1.08x0.95mm_HandSolder
D5: PMEG4002EJ; D_SOD-323F
J3: Conn_01x07; PinHeader_1x07_P1.27mm_Vertical
J9: Conn_01x04; PinHeader_1x04_P2.54mm_Vertical
J10: Conn_01x07; PinHeader_1x07_P2.54mm_Vertical
R7, R8, R9, R10: 0R; R_0603_1608Metric_Pad0.98x0.95mm_HandSolder
R11, R12: 1M; R_0603_1608Metric_Pad0.98x0.95mm_HandSolder
R13, R14: 4k7; R_0603_1608Metric_Pad0.98x0.95mm_HandSolder
R15: 10k; R_0603_1608Metric_Pad0.98x0.95mm_HandSolder
R16, R17: 1k; R_0603_1608Metric_Pad0.98x0.95mm_HandSolder
SW1: PTS526
TP1, TP2, TP4, TP10, TP11, TP12, TP13, TP15, TP21, TP22, TP23, TP24: TestPoint; TestPoint_Pad_D1.0mm
U5: STM32L412RBTx; LQFP-64_10x10mm_P0.5mm
U6: AT25SF081-SSHD-X; SOIC-8_3.9x4.9mm_P1.27mm
U7: RV-3028-C7; MicroCrystal_C7_SON-8_1.5x3.2mm_P0.9mm
Y1: 9HT11-32.768KDZB-T; 9HT1132768KDZBT; Manufacturer_Part_Number 9HT11-32.768KDZB-T; Mouser Part Number 717-9HT11-32.76KDZBT

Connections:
+3.3V: C7.1, C8.1, C9.1, C10.1, C11.1, C12.1, C13.1, C14.1, J3.1, J9.1, J10.1, R13.2, R14.2, R15.2, U5.1 (VBAT), U5.13 (VDDA), U5.19 (VDD), U5.32 (VDD), U5.48 (VDDUSB), U5.64 (VDD), U6.3 (~WP/IO2), U6.7 (~HOLD/IO3), U6.8 (VCC), U7.7 (VDD); also elsewhere on the board
+5VA: R16.1; also elsewhere on the board
+BATT: R11.2; also elsewhere on the board
BLE_RX: R10.1; also elsewhere on the board
BLE_TX: R9.1; also elsewhere on the board
BTN0: U5.26 (PB0); also elsewhere on the board
BTN1: U5.27 (PB1); also elsewhere on the board
BTN2: U5.28 (PB2); also elsewhere on the board
BTN3: U5.55 (PB3); also elsewhere on the board
BTN4: U5.56 (PB4); also elsewhere on the board
CH_STAT: U5.9 (PC1); also elsewhere on the board
DBG_RX: J3.7, U5.59 (PB7)
DBG_TX: J3.6, U5.58 (PB6)
GND: BT2.2 (-), C7.2, C8.2, C9.2, C10.2, C11.2, C12.2, C13.2, C14.2, C15.2, C16.2, J3.2, J9.4, J10.7, R12.1, SW1.3, SW1.4, U5.12 (VSSA), U5.18 (VSS), U5.31 (VSS), U5.47 (VSS), U5.60 (PH3), U5.63 (VSS), U6.4 (GND), U7.5 (VSS); also elsewhere on the board
I2C1_SCL: J9.2, R13.1, U5.42 (PA9), U7.3 (SCL); also elsewhere on the board
I2C1_SDA: J9.3, R14.1, U5.43 (PA10), U7.4 (SDA); also elsewhere on the board
unnamed: BT2.1 (+), D5.2 (A)
unnamed: D5.1 (K), U7.6 (VBACKUP)
unnamed: R7.1, U5.16 (PA2)
unnamed: R8.1, U5.17 (PA3)
unnamed: TP15.1, U5.57 (PB5)
unnamed: R16.2, U5.29 (PB10)
unnamed: R17.2, U5.30 (PB11)
unnamed: TP21.1, U5.33 (PB12)
unnamed: TP22.1, U5.34 (PB13)
unnamed: TP23.1, U5.35 (PB14)
unnamed: TP24.1, U5.36 (PB15)
unnamed: R11.1, R12.2, U5.10 (PC2)
unnamed: R9.2, U5.24 (PC4)
unnamed: R10.2, U5.25 (PC5)
unnamed: TP10.1, U5.51 (PC10)
unnamed: TP11.1, U5.52 (PC11)
unnamed: TP12.1, U5.53 (PC12)
unnamed: TP13.1, U5.2 (PC13)
unnamed: C15.1, U5.3 (PC14), Y1.1
unnamed: C16.1, U5.4 (PC15), Y1.2
unnamed: TP4.1, U5.54 (PD2)
unnamed: TP2.1, U5.5 (PH0)
unnamed: TP1.1, U5.6 (PH1)
RTC_CLK: U5.8 (PC0), U7.1 (CLKOUT)
SOUND_RX: R8.2; also elsewhere on the board
SOUND_TX: R7.2; also elsewhere on the board
SPI1_CIPO: J10.5, U5.22 (PA6), U6.2 (SO/IO1)
SPI1_COPI: J10.6, U5.23 (PA7), U6.5 (SI/IO0)
SPI1_SCLK: J10.4, U5.21 (PA5), U6.6 (SCK)
STM_SWDCLK: J3.4, U5.49 (PA14)
STM_SWDIO: J3.3, U5.46 (PA13)
USB_D+: U5.45 (PA12); also elsewhere on the board
USB_D-: U5.44 (PA11); also elsewhere on the board
VBUS: R17.1; also elsewhere on the board
WHITE_PWM1: U5.14 (PA0); also elsewhere on the board
WHITE_PWM2: U5.15 (PA1); also elsewhere on the board
~IS_INTB1: U5.38 (PC7); also elsewhere on the board
~IS_INTB2: U5.62 (PB9); also elsewhere on the board
~IS_SDB1: U5.37 (PC6); also elsewhere on the board
~IS_SDB2: U5.61 (PB8); also elsewhere on the board
~RTC_INT: U5.39 (PC8), U7.2 (~INT)
~SPI1_CS1: J10.2, U5.41 (PA8)
~SPI1_CS2: J10.3, U5.50 (PA15)
~SPI1_CS: U5.20 (PA4), U6.1 (~CS)
~STM_RST: J3.5, R15.1, SW1.1, SW1.2, U5.7 (NRST)

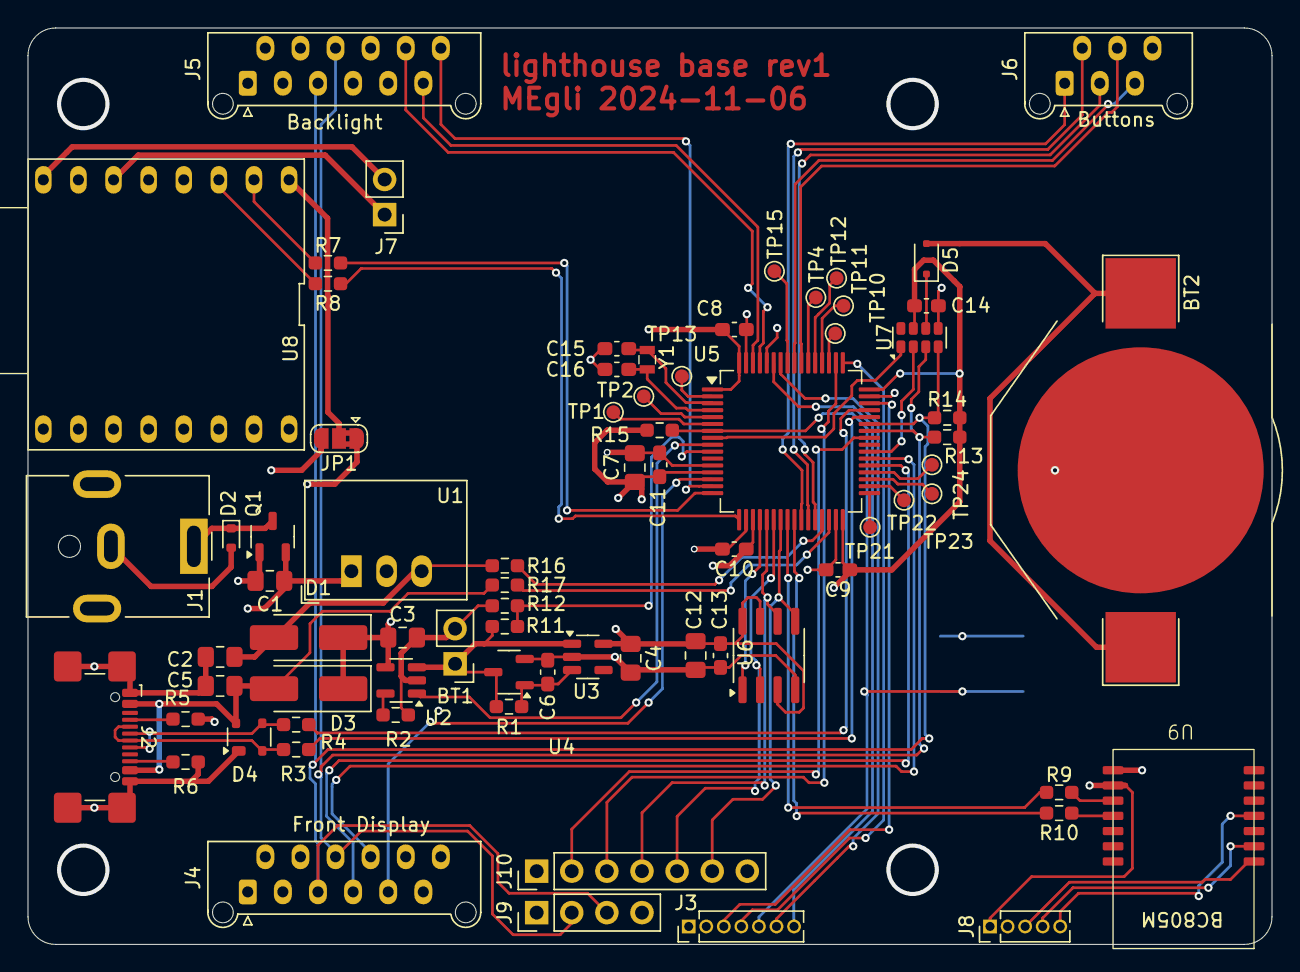
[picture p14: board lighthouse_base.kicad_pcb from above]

Board: 4 copper layers, 90.0 x 66.3 mm, 75 parts (1 on the bottom side), 76 nets.

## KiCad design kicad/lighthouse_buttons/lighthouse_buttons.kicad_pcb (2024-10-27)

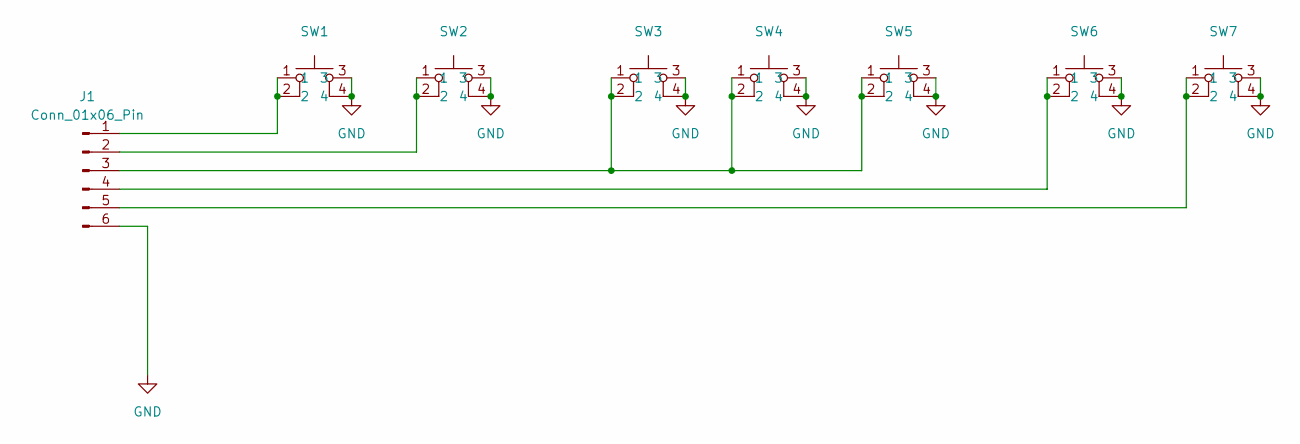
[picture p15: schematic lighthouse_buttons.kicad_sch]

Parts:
J1: Conn_01x06_Pin; con_1x6_1.27mm_long_pads
SW1, SW2, SW3, SW4, SW5, SW6, SW7: PTS526

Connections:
GND: J1.6, SW1.3, SW1.4, SW2.3, SW2.4, SW3.3, SW3.4, SW4.3, SW4.4, SW5.3, SW5.4, SW6.3, SW6.4, SW7.3, SW7.4
unnamed: J1.1, SW1.1, SW1.2
unnamed: J1.2, SW2.1, SW2.2
unnamed: J1.3, SW3.1, SW3.2, SW4.1, SW4.2, SW5.1, SW5.2
unnamed: J1.4, SW6.1, SW6.2
unnamed: J1.5, SW7.1, SW7.2

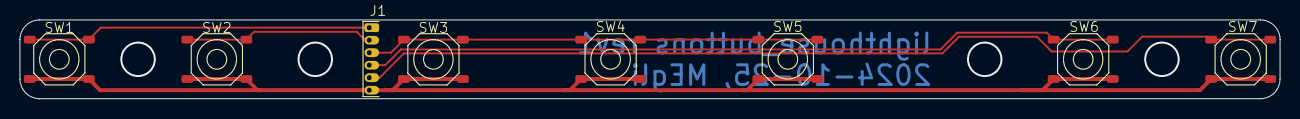
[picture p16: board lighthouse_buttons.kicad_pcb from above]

Board: 2 copper layers, 128.0 x 8.0 mm, 8 parts (0 on the bottom side), 6 nets.

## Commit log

2024-05-15 added readme + started buoy model
    [buoy.scad, parts.scad]
2024-05-15 1st version of buoy case done, try it out
    [buoy.scad, buoy_v1.0.3mf, buoy_v1.0.stl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]
2024-05-15 added buoy schematics, not 100 % done yet
    [buoy.scad, parts.scad]
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2024-05-15 added cad display test
    [displaytest.scad, displaytest_rot30.scad, parts.scad]
2024-05-23 add display
    [display.scad, displayparts.scad]
2024-05-23 added 2nd version of display covers
    [display.scad, displayparts.scad, displaytest.scad]
2024-05-23 started with case for lighthouse
    [lighthousecase.scad]
2024-05-25 added 60° side
    [display.scad, displayparts.scad, lighthousecase.scad]
2024-05-25 renamed file displayparts.scad to hexagonparts.scad
    also put led parts into ledparts.scad
    [display.scad, displayparts.scad, hexagonparts.scad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]
2024-05-25 started putting front together
    [display.scad, hexagonparts.scad, lighthousecase.scad]
2024-05-26 simpler version of the side parts created
    [hexagonparts.scad, lighthousecase.scad]
2024-05-28 bottom plate + buttons
    [buttons.scad, display.scad, hexagonparts.scad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]
2024-05-29 defined pcbs and buttons
    and separated parts into files according to its function
    [buttons.scad, display.scad, electronics.scad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]
2024-05-29 added edge stiffener 60°
    [lighthousecase.scad, m3screw.scad, panels.scad]
2024-05-30 added PLFA-M3-1 press fit inserts to mount side panels
    also added mounting sides
    also added base pcb
    [lighthousecase.scad, m3screw.scad, panels.scad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]
2024-05-30 all mounts added and placed
    [panels.scad, pcbs.scad]
2024-06-01 almost every part 3d designed, move to pcbs now
    [display.scad, hexagonparts.scad, lighthousecase.scad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]
2024-06-02 export created 3d parts
    [lighthousecase.scad, lighthouseexport.scad, pcbs.scad]
2024-06-02 added center marking to led spacer
    [display.scad, hexagonparts.scad, lighthouseexport.scad]
2024-06-02 started display pcb
    [lighthouse_display.kicad_pcb, lighthouse_display.kicad_sch]
2024-06-02 added lib
    [display.scad, lighthouse_display.kicad_pcb, lighthouse_display.kicad_sch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]
2024-06-03 white LED driver TPS61176RTER added in lib and sch
    [lighthouse_display.kicad_sch, lighthouse_display_leds.kicad_sch]
2024-06-06 much ado about LEDs :-)
    [lighthouse_display.kicad_sch, lighthouse_display_leds.kicad_sch]
2024-06-12 sch: all leds connected, also set all footprints
    [lighthouse_display.kicad_pcb, lighthouse_display.kicad_sch, lighthouse_display_leds.kicad_sch]
2024-06-19 started lighthouse base pcb
    [NINA-B312.step, lighthouse_base.kicad_pcb, lighthouse_base.kicad_sch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]
2024-09-25 hw display placed red and white leds
    [lighthouse_display.kicad_pcb, lighthouse_display.kicad_sch]
2024-10-07 places both led drivers, started routing
    [lighthouse_display.kicad_pcb, lighthouse_display.kicad_sch, lighthouse_display_leds.kicad_sch]
2024-10-09 red leds routing, not done yet
    [lighthouse_display.kicad_pcb]
2024-10-10 use 7*6 white LEDs in a row now, almost all leds connected
    [lighthouse_display.kicad_pcb, lighthouse_display.kicad_sch, lighthouse_display_leds.kicad_sch]
2024-10-10 100% routed
    [lighthouse_display.kicad_pcb, lighthouse_display.kicad_sch]
2024-10-27 started with button pcb
    [lighthouse_buttons.kicad_pcb, lighthouse_buttons.kicad_sch, lighthouse_display.kicad_pcb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]
2024-10-27 hardware for lighthouse display rev1 and button rev1 done
    [lighthouse_buttons.kicad_pcb, lighthouse_display.kicad_pcb, lighthouse_display.kicad_sch]
2024-10-30 added sheets for mcu and peripherials
    [lighthouse_base.kicad_sch, lighthouse_base_mcu.kicad_sch, lighthouse_periph.kicad_sch]
2024-10-30 added FPPlayer and BC805M BLE Module
    [lighthouse_base_mcu.kicad_sch, lighthouse_periph.kicad_sch]
2024-10-30 schema v1 done
    [lighthouse_base.kicad_sch, lighthouse_base_mcu.kicad_sch, lighthouse_periph.kicad_sch]
2024-11-02 schematics done
    [lighthouse_base.kicad_sch, lighthouse_base_mcu.kicad_sch, lighthouse_periph.kicad_sch]
2024-11-02 started with pcb lighthouse_base
    [lighthouse_base.kicad_pcb, lighthouse_base.kicad_sch, lighthouse_base_mcu.kicad_sch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]
2024-11-06 lighthouse base rev 1 done
    [lighthouse_base.kicad_pcb, lighthouse_base_mcu.kicad_sch]
2025-09-28 mv files from rev0 to rev0/
    [lighthouse_base.kicad_pcb, lighthouse_base.kicad_sch, lighthouse_base_mcu.kicad_sch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]
2025-09-28 rev1: added 32 kHz XTAL, interrupt signals for VBUS + +5V, ... many more
    [9HT11-32.768KDZB-T.stp, lighthouse_base.kicad_pcb, lighthouse_base.kicad_sch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]
2025-10-01 clean up libs
    [9HT11-32.768KDZB-T.stp]
2025-10-01 display rev0, moved files
    [lighthouse_display.kicad_pcb, lighthouse_display.kicad_sch, lighthouse_display_leds.kicad_sch]
2025-10-01 renamed libs + added opt3004 to lib
    [USON-6.stp, lighthouse_display.kicad_pcb, lighthouse_display.kicad_sch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]
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2025-10-02 rev1 of base + display
    [lighthouse_base.kicad_pcb, lighthouse_base.kicad_sch, lighthouse_base_mcu.kicad_sch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]
